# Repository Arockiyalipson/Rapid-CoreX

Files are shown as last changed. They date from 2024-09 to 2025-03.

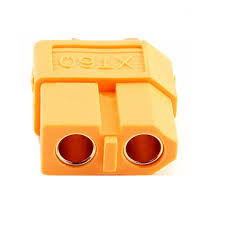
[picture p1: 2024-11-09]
Images/XT 60 FEMALE.jpg

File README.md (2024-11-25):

# Rapid_CoreX 





## Introduction

Rapid-CoreX is a versatile Rapid control prototyping (RCP) designed for embedded systems development, testing, and integration. It supports essential communication protocols and allows for easy connection and testing of various sensors or devices using MATLAB software. Rapid-CoreX is particularly useful for testing external parameters of Battery Management Systems (BMS), motor controllers, and other connected devices.

## Tools Used

- **KiCad:** Used for schematic capture and PCB layout design.
- **STM32CubeMX:** Used for setting up the pin map for the design

## Design Structure

```bash
Rapid-CoreX
        │
        ├───Design
        │
        ├───Images
        │
        ├───Library
        │   ├───Symbols
        │   ├───Footprint
        │   └───3D_Images
        ├───Manufacturing_files
        │   ├───Bom file
        │   ├───Component position files
        │   ├───Drill files
        │   ├───Gerber files
        │   └───Reference_material
        └───Reference
```

## Features

### Communication Protocols

Rapid-CoreX includes the following communication protocols for sensor connection, data collection, and interconnection:

#### Basic Protocols

- **SPI**: Serial Peripheral Interface for high-speed communication.
- **I2C**: Inter-Integrated Circuit for connecting multiple sensors.
- **UART**: Universal Asynchronous Receiver-Transmitter for serial communication.

#### Debugging

- **SWD**: Serial Wire Debug for in-circuit debugging and programming.

#### Data Collection and Interconnection Protocols

- **CAN**: Controller Area Network for real-time data exchange in automotive and industrial applications.
- **RS-485**: A robust standard for long-distance communication.
- **LIN**: Local Interconnect Network, used in automotive networks for communication between components.

All data collection protocols are isolated to ensure better protection and signal integrity.

### Communication Ports

Rapid-CoreX is equipped with various ports to facilitate connectivity:

- **2 x CAN** ports for network communication.
- **2 x RS-485** ports (USART) for long-distance and robust communication.
- **2 x LIN** ports for automotive applications.
- **1 x External SPI** ports for additional SPI device connectivity.

### GPIO Features

- **User LED**: Available for user-defined visual indication.

## Applications

Rapid-CoreX is ideal for:

- Testing external parameters of Battery Management Systems (BMS).
- Testing motor controllers.
- Integrating and testing various sensors.
- Development and testing of embedded systems that require robust and isolated communication.

## Getting Started

### Prerequisites

To use Rapid-CoreX, ensure you have the following:

- MATLAB software for interfacing and testing.
- Necessary drivers and libraries for STM32 Cortex-M4.

### Setup

1. Connect your sensors or sister devices to the appropriate communication ports on Rapid-CoreX.
2. Use MATLAB to interface with Rapid-CoreX for data collection and testing.
3. For debugging, connect through the SWD interface.

### Usage

1. Power on the Rapid-CoreX and ensure all connections are secure.
2. Implement a MATLAB Developed Algorithm in the board
3. Start collecting Data and Analyze it 

## Contact

For more information, please contact [Arockiya Lipson](https://www.linkedin.com/in/arockiya-lipson-458b12214).

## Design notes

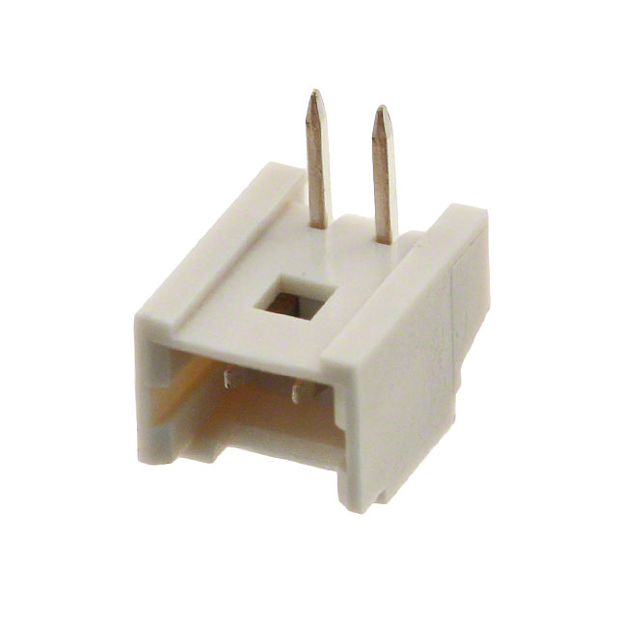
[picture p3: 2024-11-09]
Images/53048-0210_connector.jpg

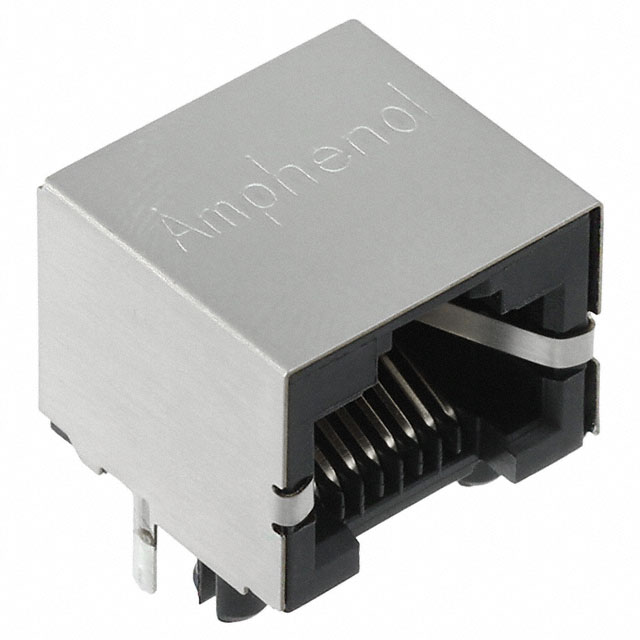
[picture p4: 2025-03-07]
Images/RJHSE5E80.jpg

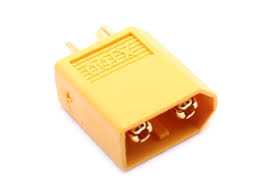
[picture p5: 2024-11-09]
Images/MALE.jpg

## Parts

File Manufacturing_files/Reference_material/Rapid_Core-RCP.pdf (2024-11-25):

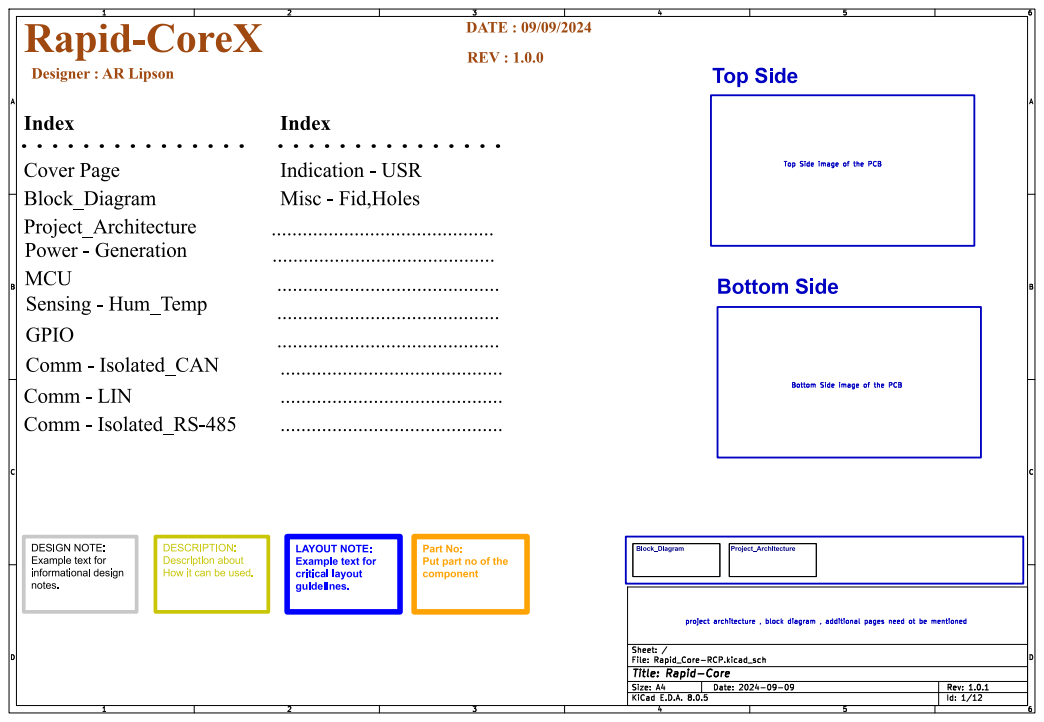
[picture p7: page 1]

Top Side image of the PCB Top Side

DESCRIPTION:
Description about
How it can be used.

Part No:
Put part no of the
component

Id: 1/12 Title: Rapid-Core

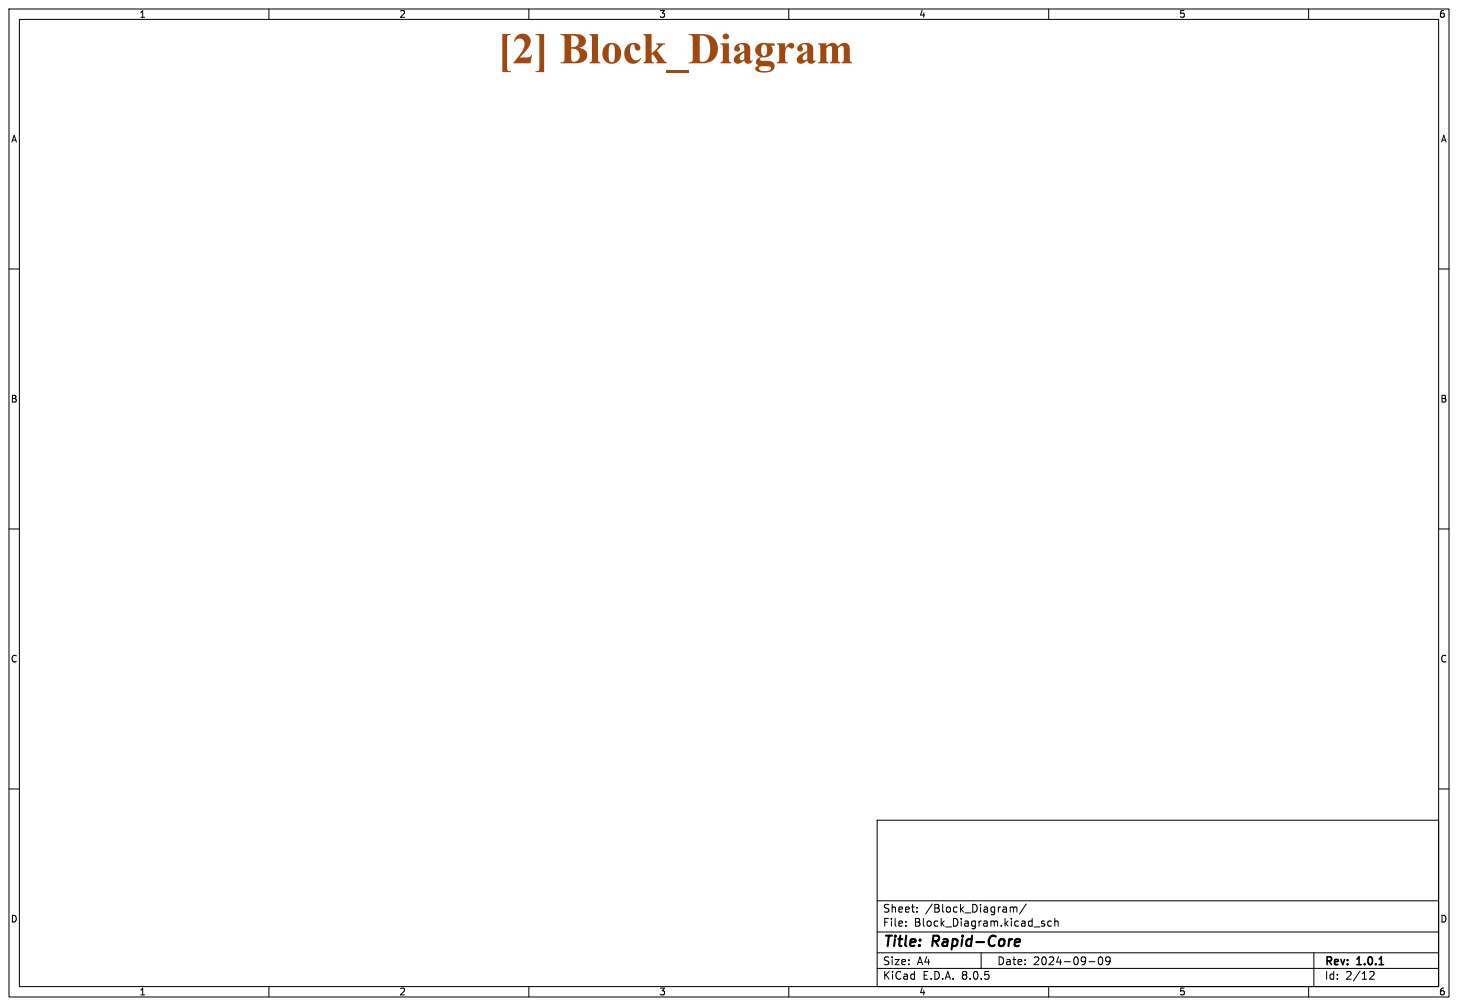
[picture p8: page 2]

File: Block_Diagram.kicad_sch Sheet: /Block_Diagram/
Id: 2/12 Title: Rapid-Core

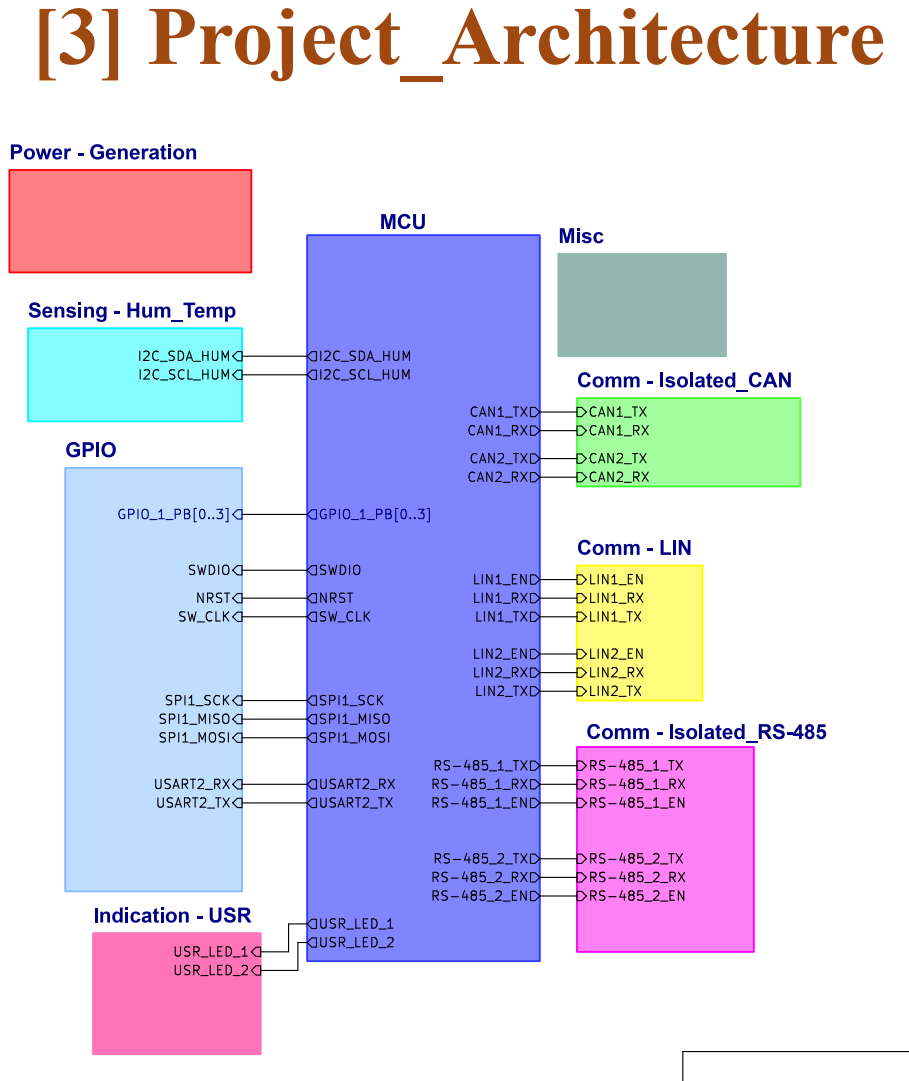
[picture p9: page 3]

RS-485_1_RX RS-485_1_TX RS-485_1_EN Comm - Isolated_RS-485

File: Project_Architecture.kicad_sch Sheet: /Project_Architecture/
Id: 3/12 Title: Rapid-Core

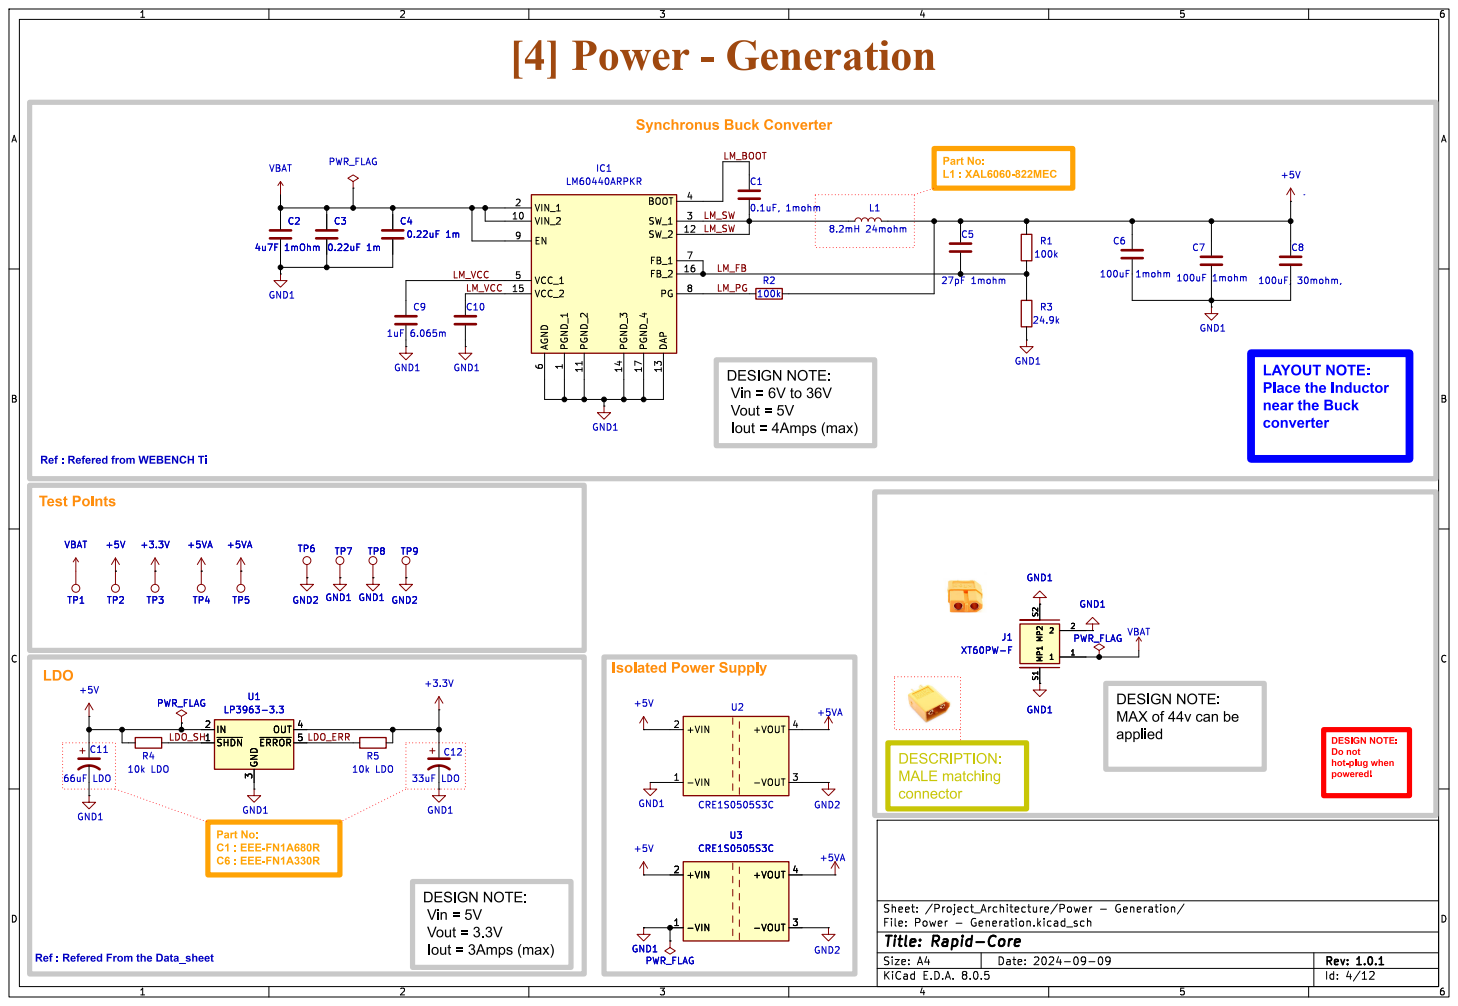
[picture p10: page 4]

LAYOUT NOTE:
Place the Inductor near the Buck

converter Part No: C1 : EEE-FN1A680R

Ref : Refered from WEBENCH Ti Test Points

MAX of 44v can be

Id: 4/12 Title: Rapid-Core

Ref : Refered From the Data_sheet

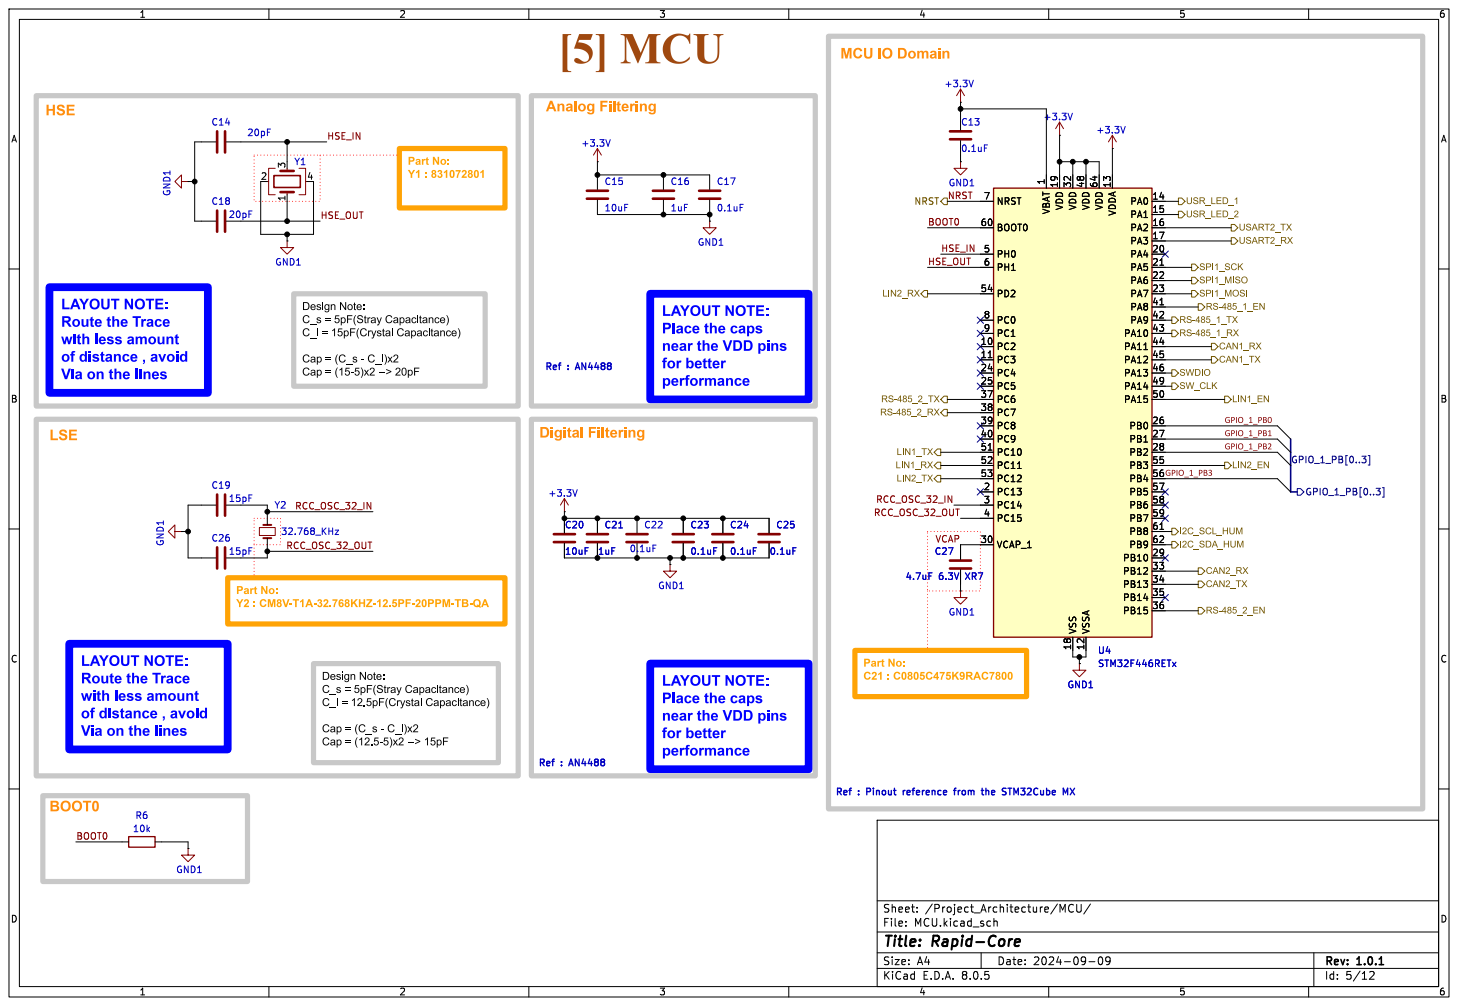
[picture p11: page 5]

1 PC2 10 PC3 11 VSSA 12 VDDA 13 PA0 14 PA1 15 PA2 16 PA3 17 VSS 18 VDD 19 PC13 2 PA4 20 PA5 21 PA6 22 PA7 23 PC4 24 PC5 25 PB0 26 PB1 27 PB2 28 PB10 29 PC14 3 VCAP_1 30 VDD 32 PB12 33 PB13 34 PB14 35 PB15 36 PC6 37 PC7 38 PC8 39 PC15 4 PC9 40 PA8 41 PA9 42 PA10 43 PA11 44 PA12 45 PA13 46 VDD 48 PA14 49 PH0 5 PA15 50 PC10 51 PC11 52 PC12 53 PD2 54 PB3 55 PB4 56 PB5 57 PB6 58 PB7 59 PH1 6 BOOT0 60 PB8 61 PB9 62 VDD 64 NRST 7 PC0 8 PC1 9 U4STM32F446RETx C23

1 PC2 10 PC3 11 VSSA 12 VDDA 13 PA0 14 PA1 15 PA2 16 PA3 17 VSS 18 VDD 19 PC13 2 PA4 20 PA5 21 PA6 22 PA7 23 PC4 24 PC5 25 PB0 26 PB1 27 PB2 28 PB10 29 PC14 3 VCAP_1 30 VDD 32 PB12 33 PB13 34 PB14 35 PB15 36 PC6 37 PC7 38 PC8 39 PC15 4 PC9 40 PA8 41 PA9 42 PA10 43 PA11 44 PA12 45 PA13 46 VDD 48 PA14 49 PH0 5 PA15 50 PC10 51 PC11 52 PC12 53 PD2 54 PB3 55 PB4 56 PB5 57 PB6 58 PB7 59 PH1 6 BOOT0 60 PB8 61 PB9 62 VDD 64 NRST 7 PC0 8 PC1 9 GND1 C23

BOOT0 Ref : Pinout reference from the STM32Cube MX BOOT0

LAYOUT NOTE:
Route the Trace
with less amount
of distance , avoid
Via on the lines

Design Note: C_s = 5pF(Stray Capacitance)

Place the caps near the VDD pins

Part No: Y2 : CM8V-T1A-32.768KHZ-12.5PF-20PPM-TB-QA

File: MCU.kicad_sch Sheet: /Project_Architecture/MCU/
Id: 5/12 Title: Rapid-Core

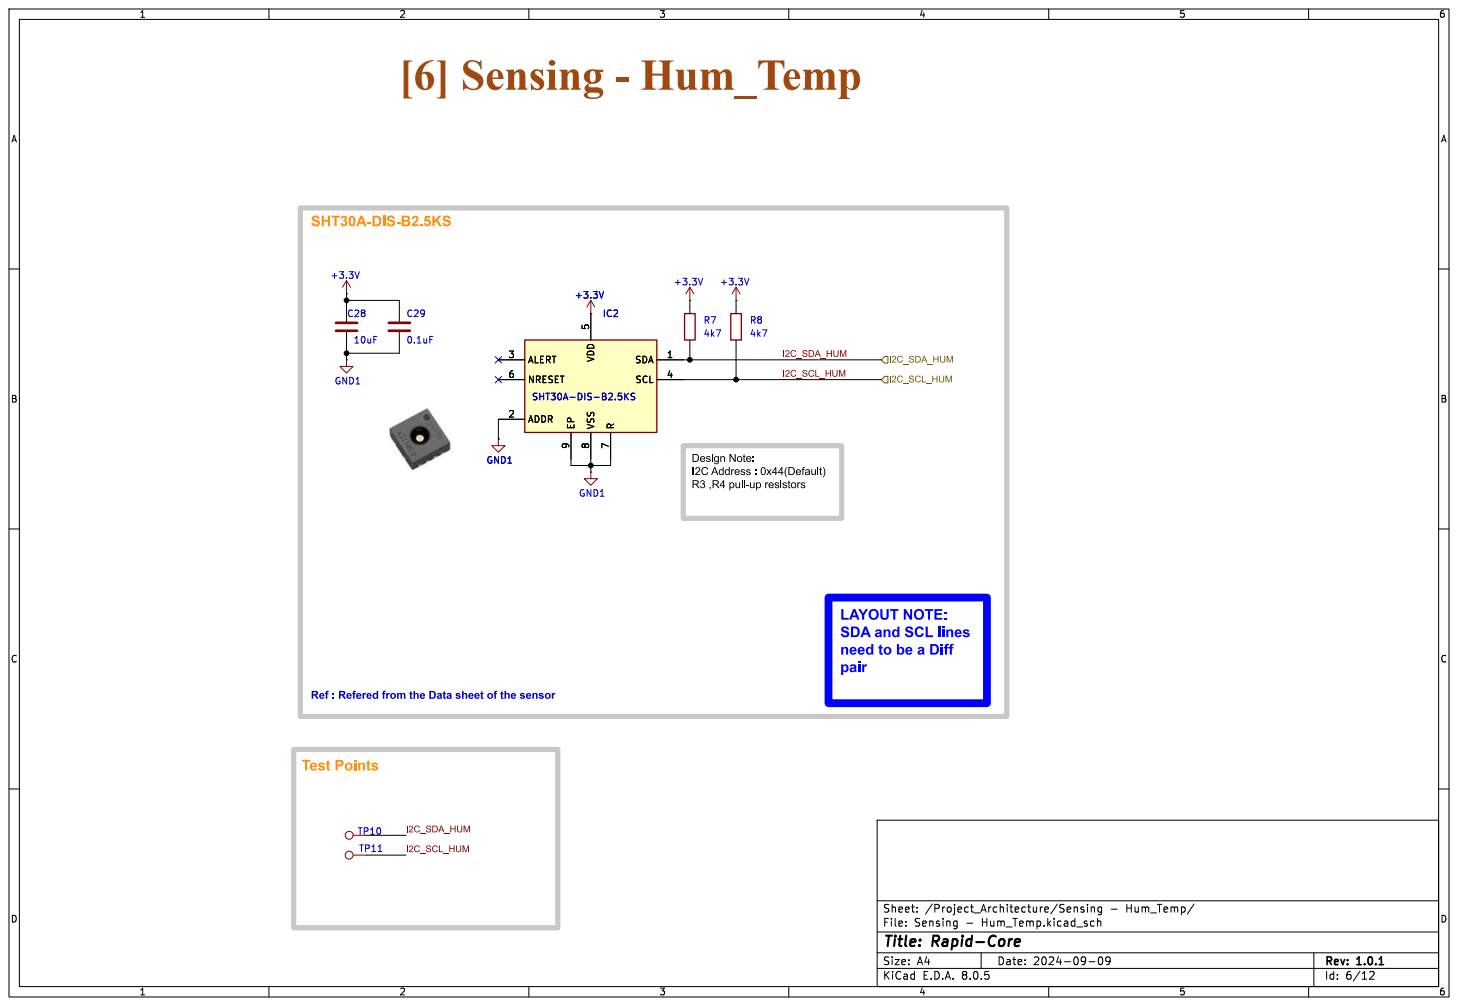
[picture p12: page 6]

SDA and SCL lines
need to be a Diff
pair

Ref : Refered from the Data sheet of the sensor Test Points

Id: 6/12 Title: Rapid-Core

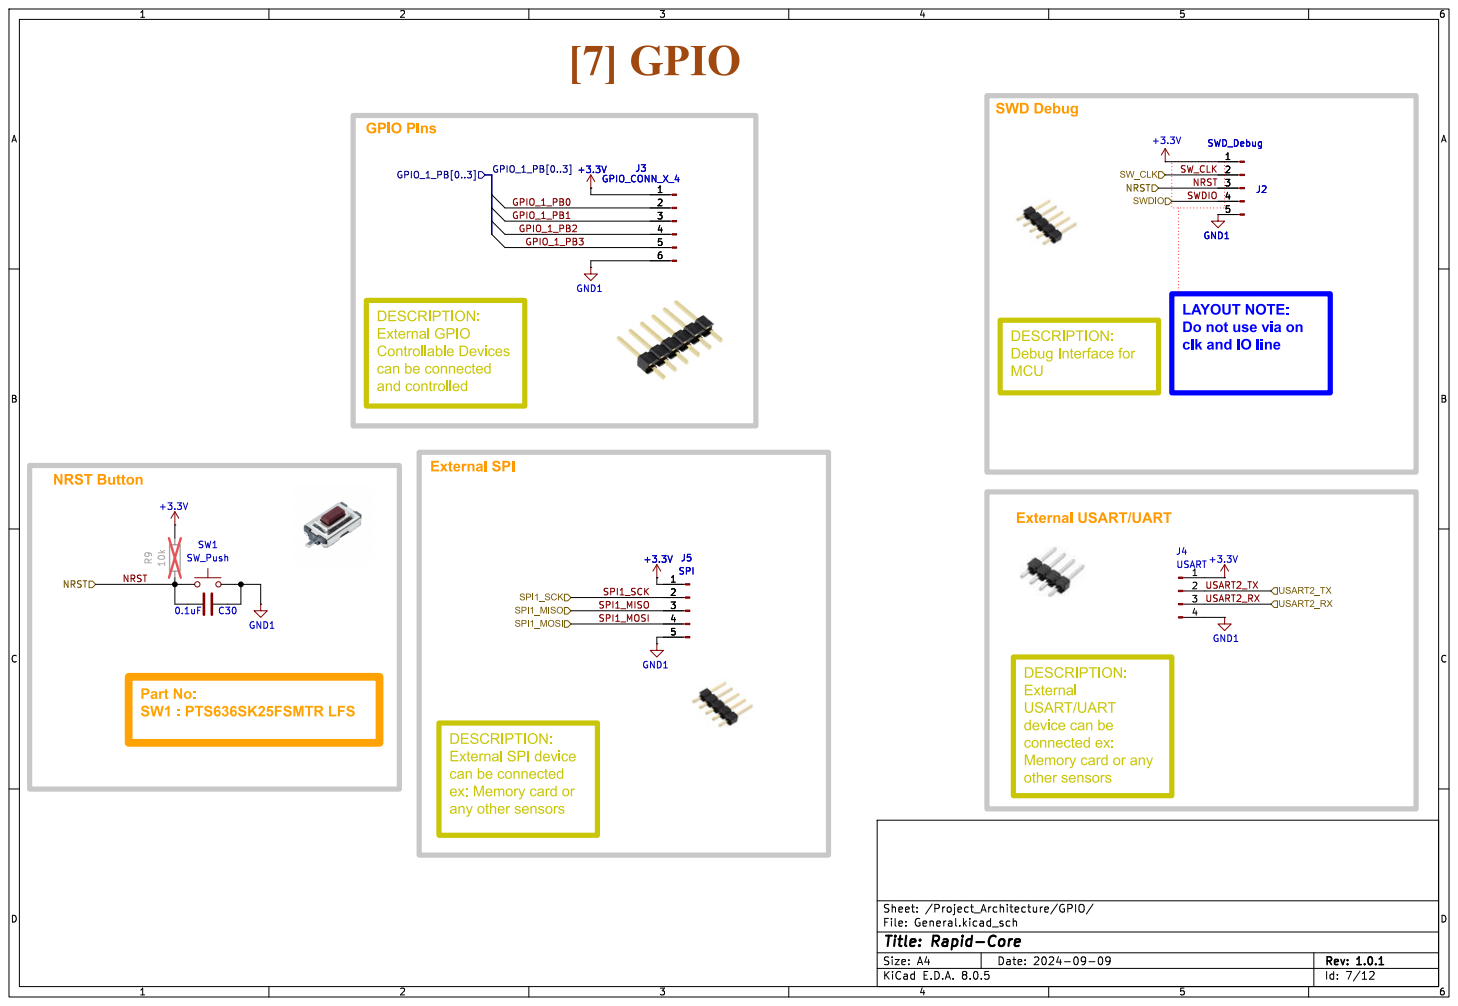
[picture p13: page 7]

SWD Debug

GPIO Pins | 5 5 6

Do not use via on

Debug Interface for | clk and IO line DESCRIPTION:

can be connected and controlled

File: General.kicad_sch Sheet: /Project_Architecture/GPIO/ GND1

DESCRIPTION:
External
USART/UART
device can be
connected ex: Memory card or any

Id: 7/12 Title: Rapid-Core

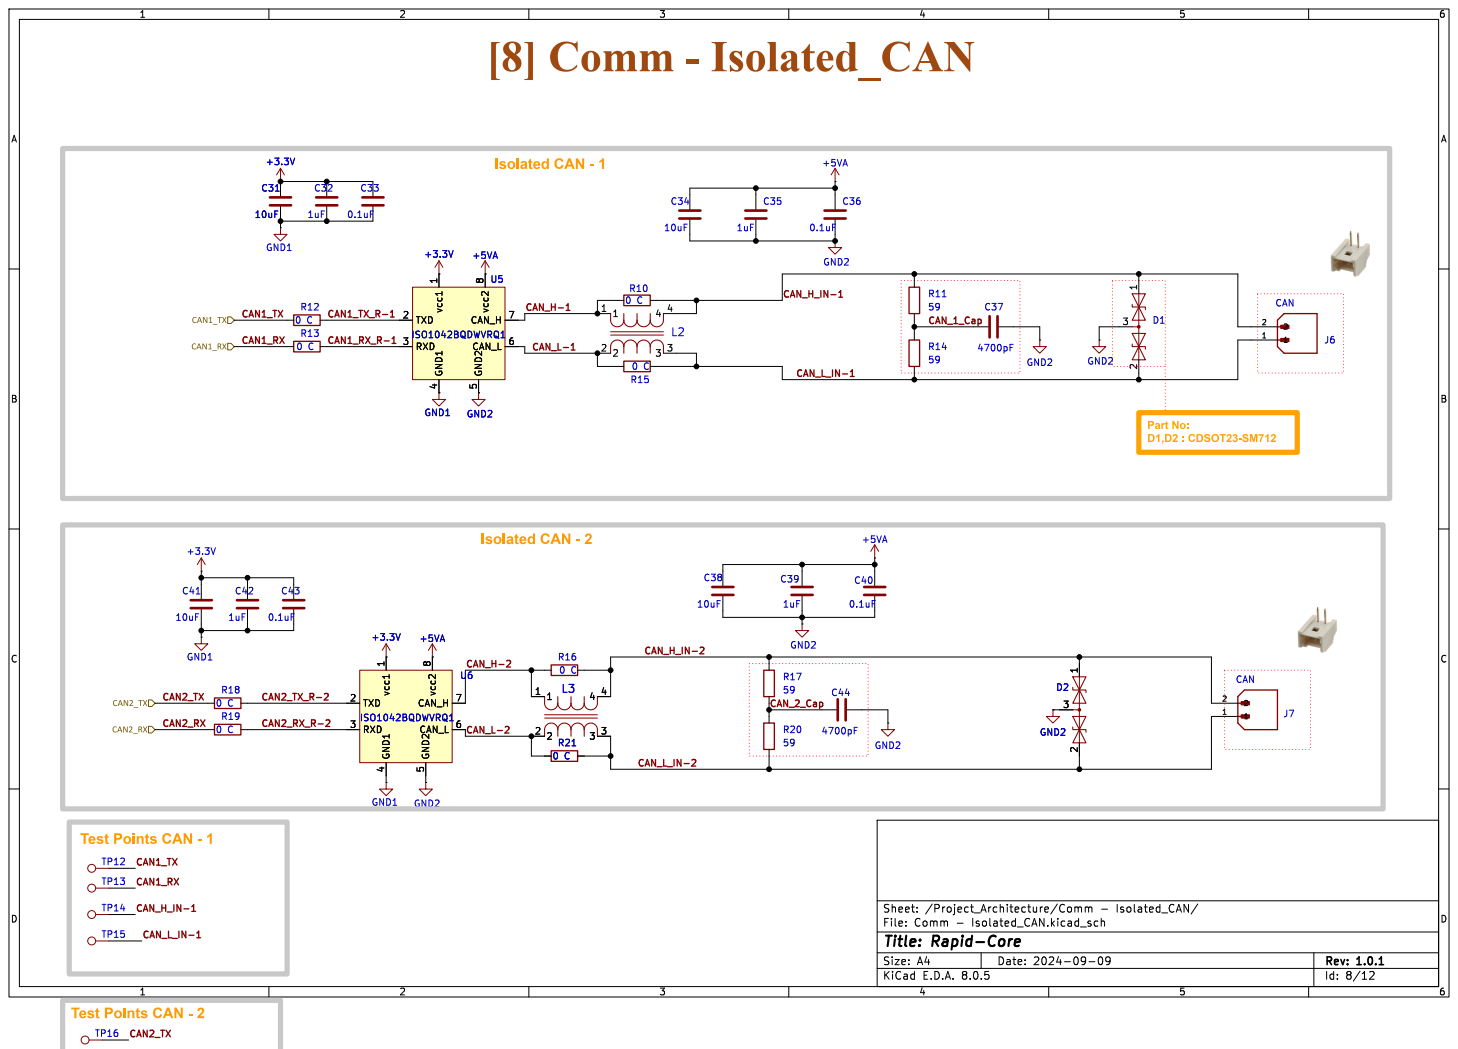
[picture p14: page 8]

Id: 8/12 Title: Rapid-Core


1. If J9 is closed the
tranceiver acts a Commander.

2. If J9 is open the

transceiver acts a Responder. Part No: D3 : 1N4448WSF-7

Id: 9/12 Title: Rapid-Core


RS-485_B_IN-1 RS-485_2_TX_R-2 Test Points RS_485 - 1

Id: 10/12 Title: Rapid-Core


LED_2_R [11]Indication- USR
Size : 0603 DESIGN NOTE : USR LED(GREEN): Vf = 2V R =(5V - 2V)/20mA = 150Ohm

Id: 11/12 Title: Rapid-Core


File: Misc.kicad_sch Sheet: /Project_Architecture/Misc/
Id: 12/12 Title: Rapid-Core

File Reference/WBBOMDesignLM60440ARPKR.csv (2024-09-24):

Part | Manufacturer | Part Number | Quantity | Price ($) | Footprint (mm²) | Description
Cboot | MuRata | GRM155R71A104KA01D | 1 | 0.01 | 3 | Cap: 100 nF Total Derated Cap: 100 nF VDC: 10 V ESR: 1 mΩ Package: 0402
Cvcc | MuRata | GRM188R60J105KA01D | 1 | 0.01 | 4.68 | Cap: 1 µF Total Derated Cap: 1 µF VDC: 6.3 V ESR: 6.07 mΩ Package: 0
Cout | MuRata | GRM32EC80J107ME20L | 2 | 0.17 | 14.7 | Cap: 100 µF Total Derated Cap: 130 µF VDC: 6.3 V ESR: 1 mΩ Package: 1210
Coutx | MuRata | GRM188R71C104KA01D | 1 | 0.01 | 4.68 | Cap: 100 nF Total Derated Cap: 100 nF VDC: 16 V ESR: 30 mΩ Package: 0603
Cin | TDK | C2012X5R1H475K125AB | 1 | 0.12 | 6.75 | Cap: 4.7 µF Total Derated Cap: 1.2 µF VDC: 50 V ESR: 1 mΩ Package: 0805
U1 | Texas Instruments | LM60440ARPKR | 1 | 0.903 | 12
L1 | Coilcraft | XAL6060-822MEB | 1 | 0.82 | 71.56 | L: 8.2 µH DCR: 24 mΩ IDC: 8 A
Cinx | Taiyo Yuden | UMK212B7224KG-T | 1 | 0.02 | 6.75 | Cap: 220 nF Total Derated Cap: 220 nF VDC: 50 V ESR: 1 mΩ Package: 0805
Cinx_ch1 | Taiyo Yuden | UMK212B7224KG-T | 1 | 0.02 | 6.75 | Cap: 220 nF Total Derated Cap: 220 nF VDC: 50 V ESR: 1 mΩ Package: 0805
Rfbt | Vishay-Dale | CRCW0402100KFKED | 1 | 0.01 | 3 | Resistance: 100 kΩ Tolerance: 1.0% Power: 63 mW
Rfbb | Vishay-Dale | CRCW040243K2FKED | 1 | 0.01 | 3 | Resistance: 43.2 kΩ Tolerance: 1.0% Power: 63 mW
Rpg | Vishay-Dale | CRCW0603100KFKEA | 1 | 0.01 | 4.68 | Resistance: 100 kΩ Tolerance: 1.0% Power: 100 mW
Cff | MuRata | GRM1555C1H270JA01D | 1 | 0.01 | 3 | Cap: 27 pF Total Derated Cap: 27 pF VDC: 50 V ESR: 1 mΩ Package: 0402

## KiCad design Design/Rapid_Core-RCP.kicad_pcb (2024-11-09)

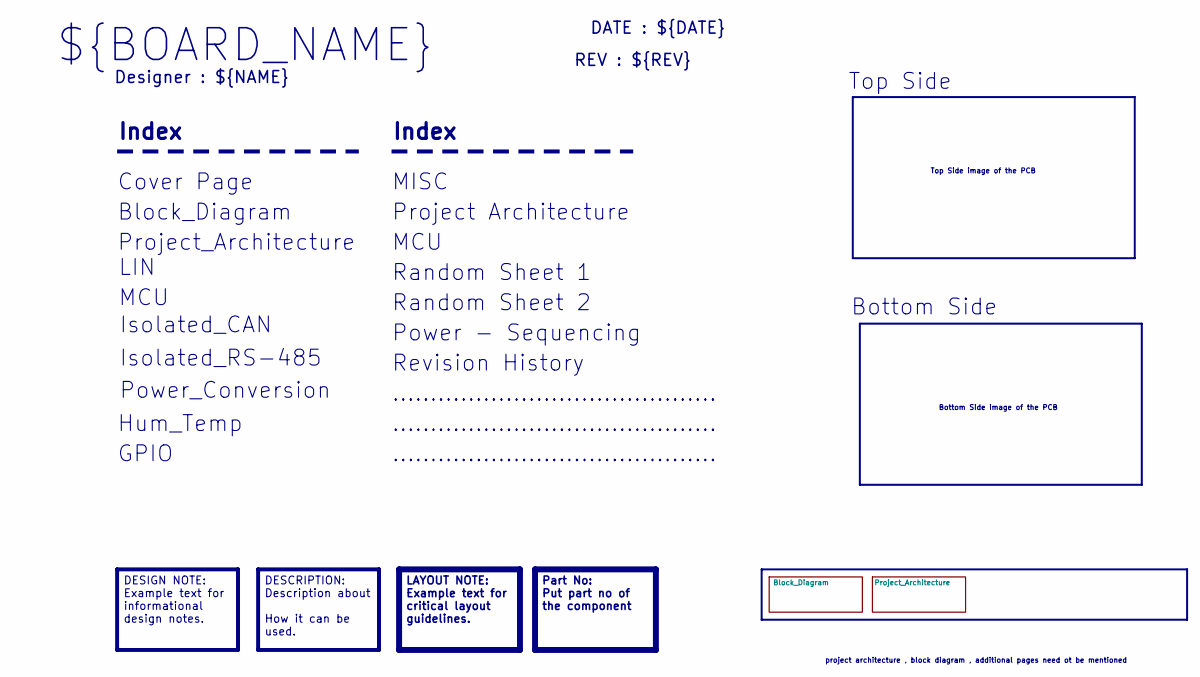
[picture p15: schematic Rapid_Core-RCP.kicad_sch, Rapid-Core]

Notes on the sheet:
DESCRIPTION: Description about How it can be used.
Part No: Put part no of the component
DESIGN NOTE: Example text for informational design notes.
LAYOUT NOTE: Example text for critical layout guidelines.
...........................................
Top Side image of the PCB
MISC
Power_Conversion
Designer : ${NAME}
Random Sheet 1
Revision History
Hum_Temp
project architecture , block diagram , additional pages need ot be mentioned
Cover Page
Power - Sequencing
Bottom Side image of the PCB
DATE : ${DATE}
Project_Architecture
Top Side
Isolated_RS-485
${BOARD_NAME}
Index
Bottom Side
REV : ${REV}
GPIO
Isolated_CAN
Random Sheet 2
MCU
Project Architecture
LIN
Block_Diagram

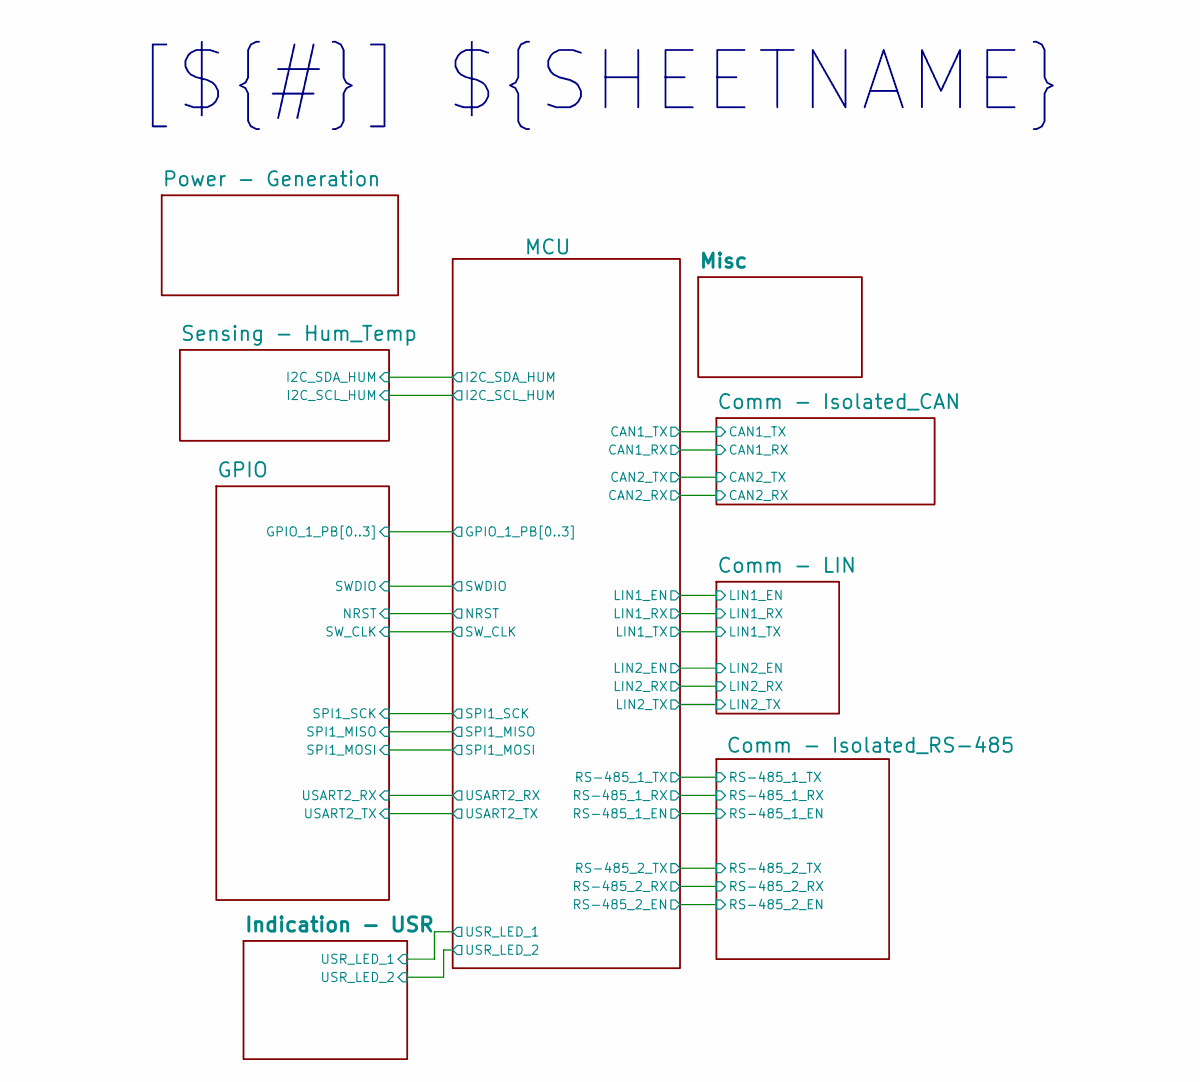
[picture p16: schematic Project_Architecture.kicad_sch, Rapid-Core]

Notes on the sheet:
[${#}] ${SHEETNAME}

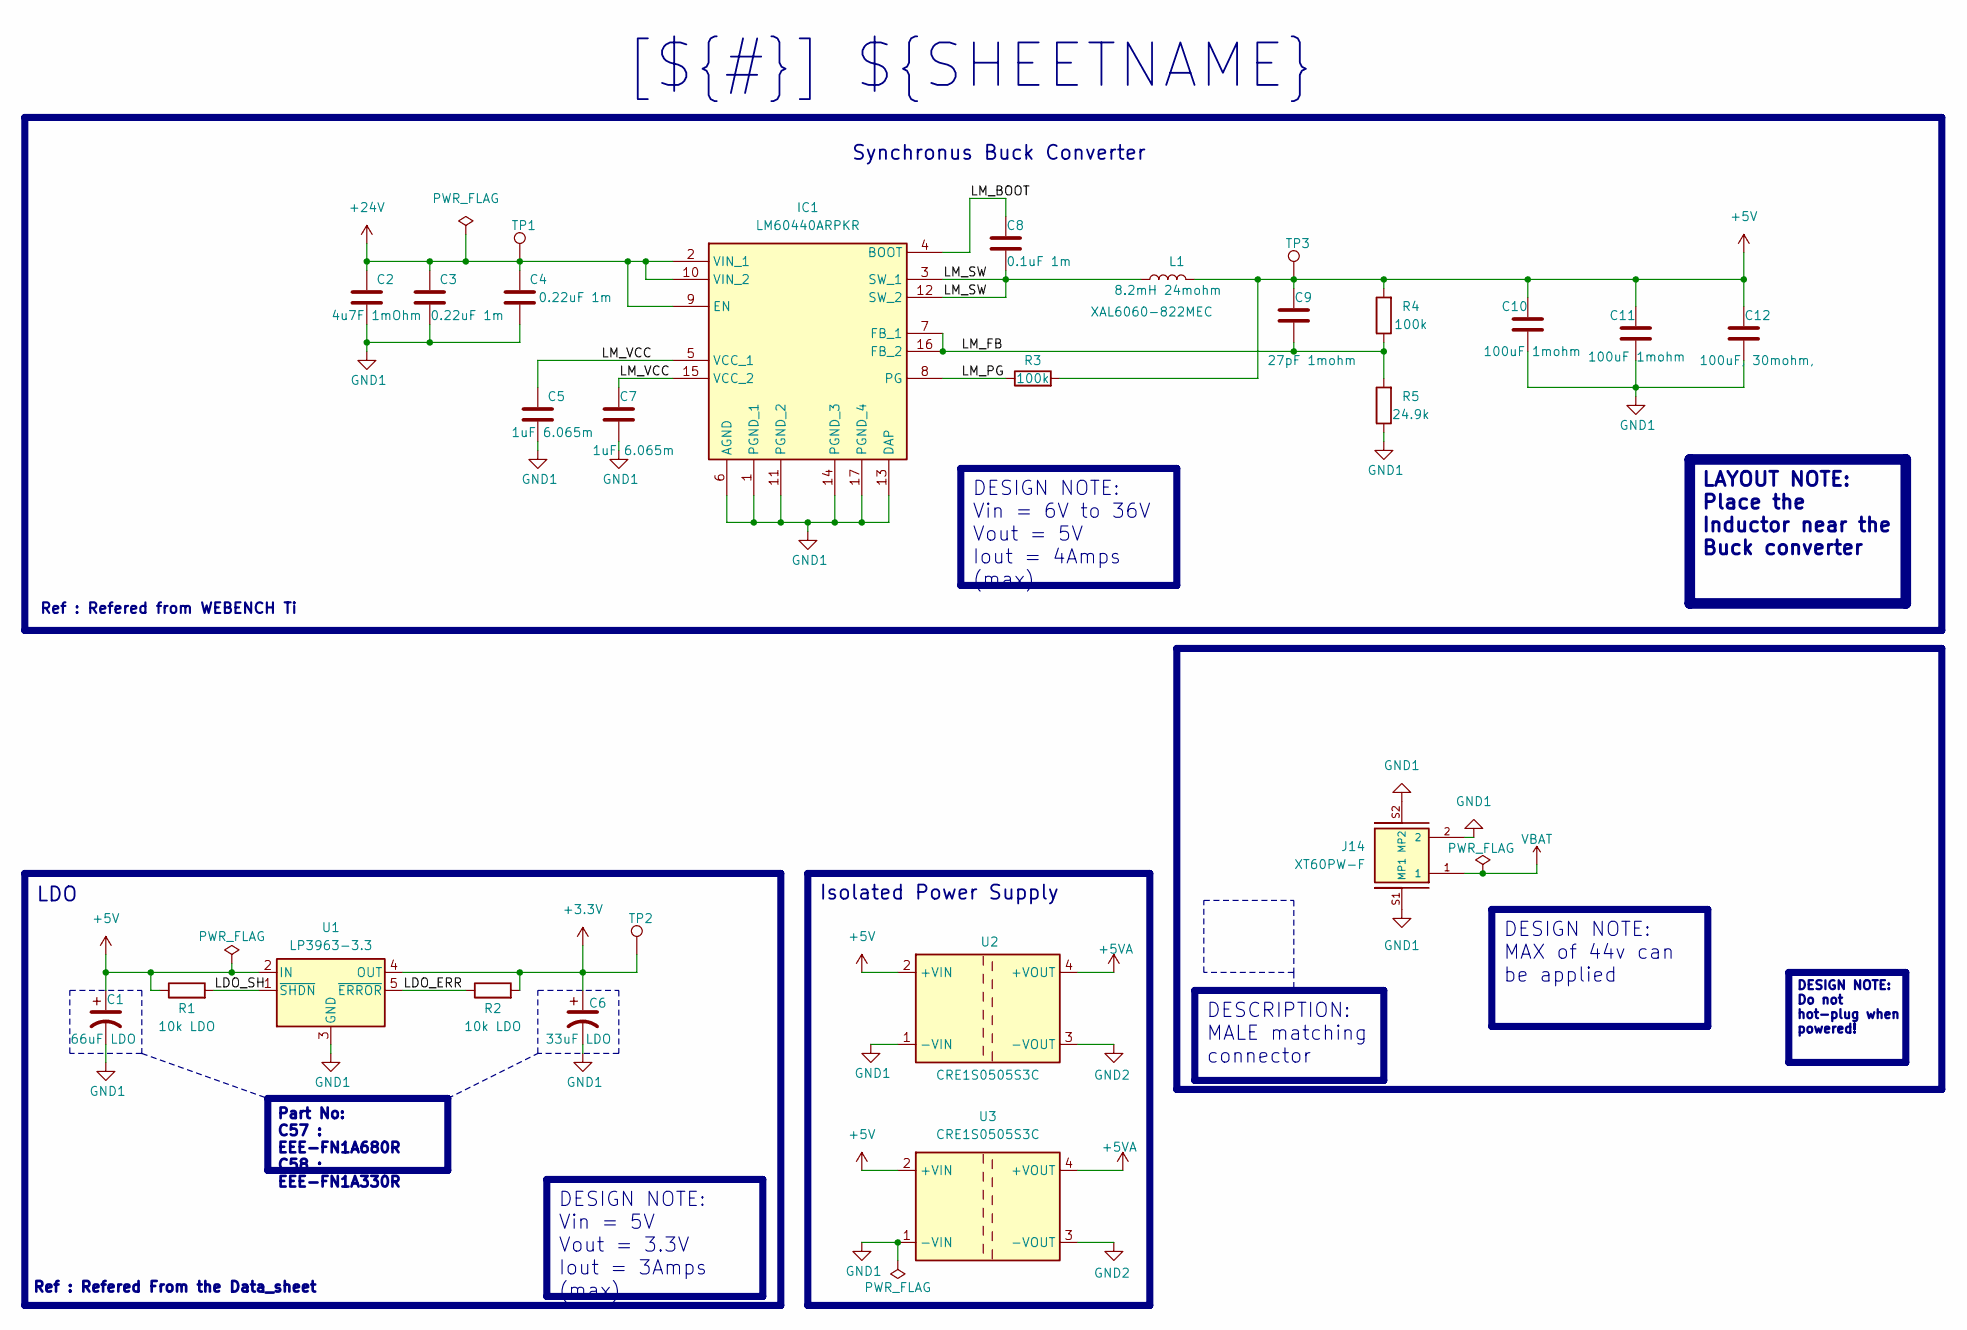
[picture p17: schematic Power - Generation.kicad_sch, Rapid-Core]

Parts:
C1: 66uF LDO; CP_Elec_5x5.8
C2: 4u7F 1mOhm; C_0805_2012Metric_Pad1.18x1.45mm_HandSolder
C3, C4: 0.22uF 1m; C_0603_1608Metric_Pad1.08x0.95mm_HandSolder
C5, C7: 1uF 6.065m; C_0603_1608Metric_Pad1.08x0.95mm_HandSolder
C6: 33uF LDO; CP_Elec_4x5.8
C8: 0.1uF 1m; C_0603_1608Metric_Pad1.08x0.95mm_HandSolder
C9: 27pF 1mohm; C_0805_2012Metric_Pad1.18x1.45mm_HandSolder
C10, C11: 100uF 1mohm; C_0805_2012Metric_Pad1.18x1.45mm_HandSolder
C12: 100uF, 30mohm,; C_0805_2012Metric_Pad1.18x1.45mm_HandSolder
IC1: LM60440ARPKR; LM60440AQRPKRQ1; Mouser Part Number 595-LM60440ARPKR
J14: XT60PW-F; AMASS_XT60PW-F
L1: 8.2mH 24mohm; L_Coilcraft_XAL6060-XXX; MANUFACTURER PART NO XAL6060-822MEC
R1, R2: 10k LDO; R_0805_2012Metric_Pad1.20x1.40mm_HandSolder
R3, R4: 100k; R_0805_2012Metric_Pad1.20x1.40mm_HandSolder
R5: 24.9k; R_0805_2012Metric_Pad1.20x1.40mm_HandSolder
TP1, TP2, TP3: TestPoint; TestPoint_Pad_D1.0mm
U1: LP3963-3.3; TO-263-5_TabPin3
U2, U3: CRE1S0505S3C; Converter_DCDC_Murata_CRE1xxxxxx3C_THT

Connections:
+3.3V: C6.1, R2.2, TP2.1, U1.4 (OUT); also elsewhere on the board
+5V: C1.1, C9.1, C10.1, C11.1, C12.1, L1.2, R1.1, R3.2, R4.2, TP3.1, U1.2 (IN), U2.2 (+VIN), U3.2 (+VIN); also elsewhere on the board
+5VA: U2.4 (+VOUT), U3.4 (+VOUT); also elsewhere on the board
+24V: C2.1, C3.1, C4.1, IC1.2 (VIN_1), IC1.9 (EN), IC1.10 (VIN_2), TP1.1
/Project_Architecture/Power - Generation/LDO_ERR: R2.1, U1.5 (~ERROR)
/Project_Architecture/Power - Generation/LDO_SH: R1.2, U1.1 (~SHDN)
/Project_Architecture/Power - Generation/LM_BOOT: C8.1, IC1.4 (BOOT)
/Project_Architecture/Power - Generation/LM_FB: C9.2, IC1.7 (FB_1), IC1.16 (FB_2), R4.1, R5.2
/Project_Architecture/Power - Generation/LM_PG: IC1.8 (PG), R3.1
/Project_Architecture/Power - Generation/LM_SW: C8.2, IC1.3 (SW_1), IC1.12 (SW_2), L1.1
/Project_Architecture/Power - Generation/LM_VCC: C5.1, C7.1, IC1.5 (VCC_1), IC1.15 (VCC_2)
GND1: C1.2, C2.2, C3.2, C4.2, C5.2, C6.2, C7.2, C10.2, C11.2, C12.2, IC1.1 (PGND_1), IC1.6 (AGND), IC1.11 (PGND_2), IC1.13 (DAP), IC1.14 (PGND_3), IC1.17 (PGND_4), J14.2, J14.S1 (MP1), J14.S2 (MP2), R5.1, U1.3 (GND), U2.1 (-VIN), U3.1 (-VIN); also elsewhere on the board
GND2: U2.3 (-VOUT), U3.3 (-VOUT); also elsewhere on the board
VBAT: J14.1

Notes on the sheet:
DESIGN NOTE: Vin = 5V Vout = 3.3V Iout = 3Amps (max)
DESIGN NOTE: Vin = 6V to 36V Vout = 5V Iout = 4Amps (max)
DESIGN NOTE: MAX of 44v can be applied
LAYOUT NOTE: Place the Inductor near the Buck converter
Part No: C57 : EEE-FN1A680R C58 : EEE-FN1A330R
DESCRIPTION: MALE matching connector
DESIGN NOTE: Do not hot-plug when powered!
[${#}] ${SHEETNAME}
Isolated Power Supply
LDO
Ref : Refered From the Data_sheet
Synchronus Buck Converter
Ref : Refered from WEBENCH Ti

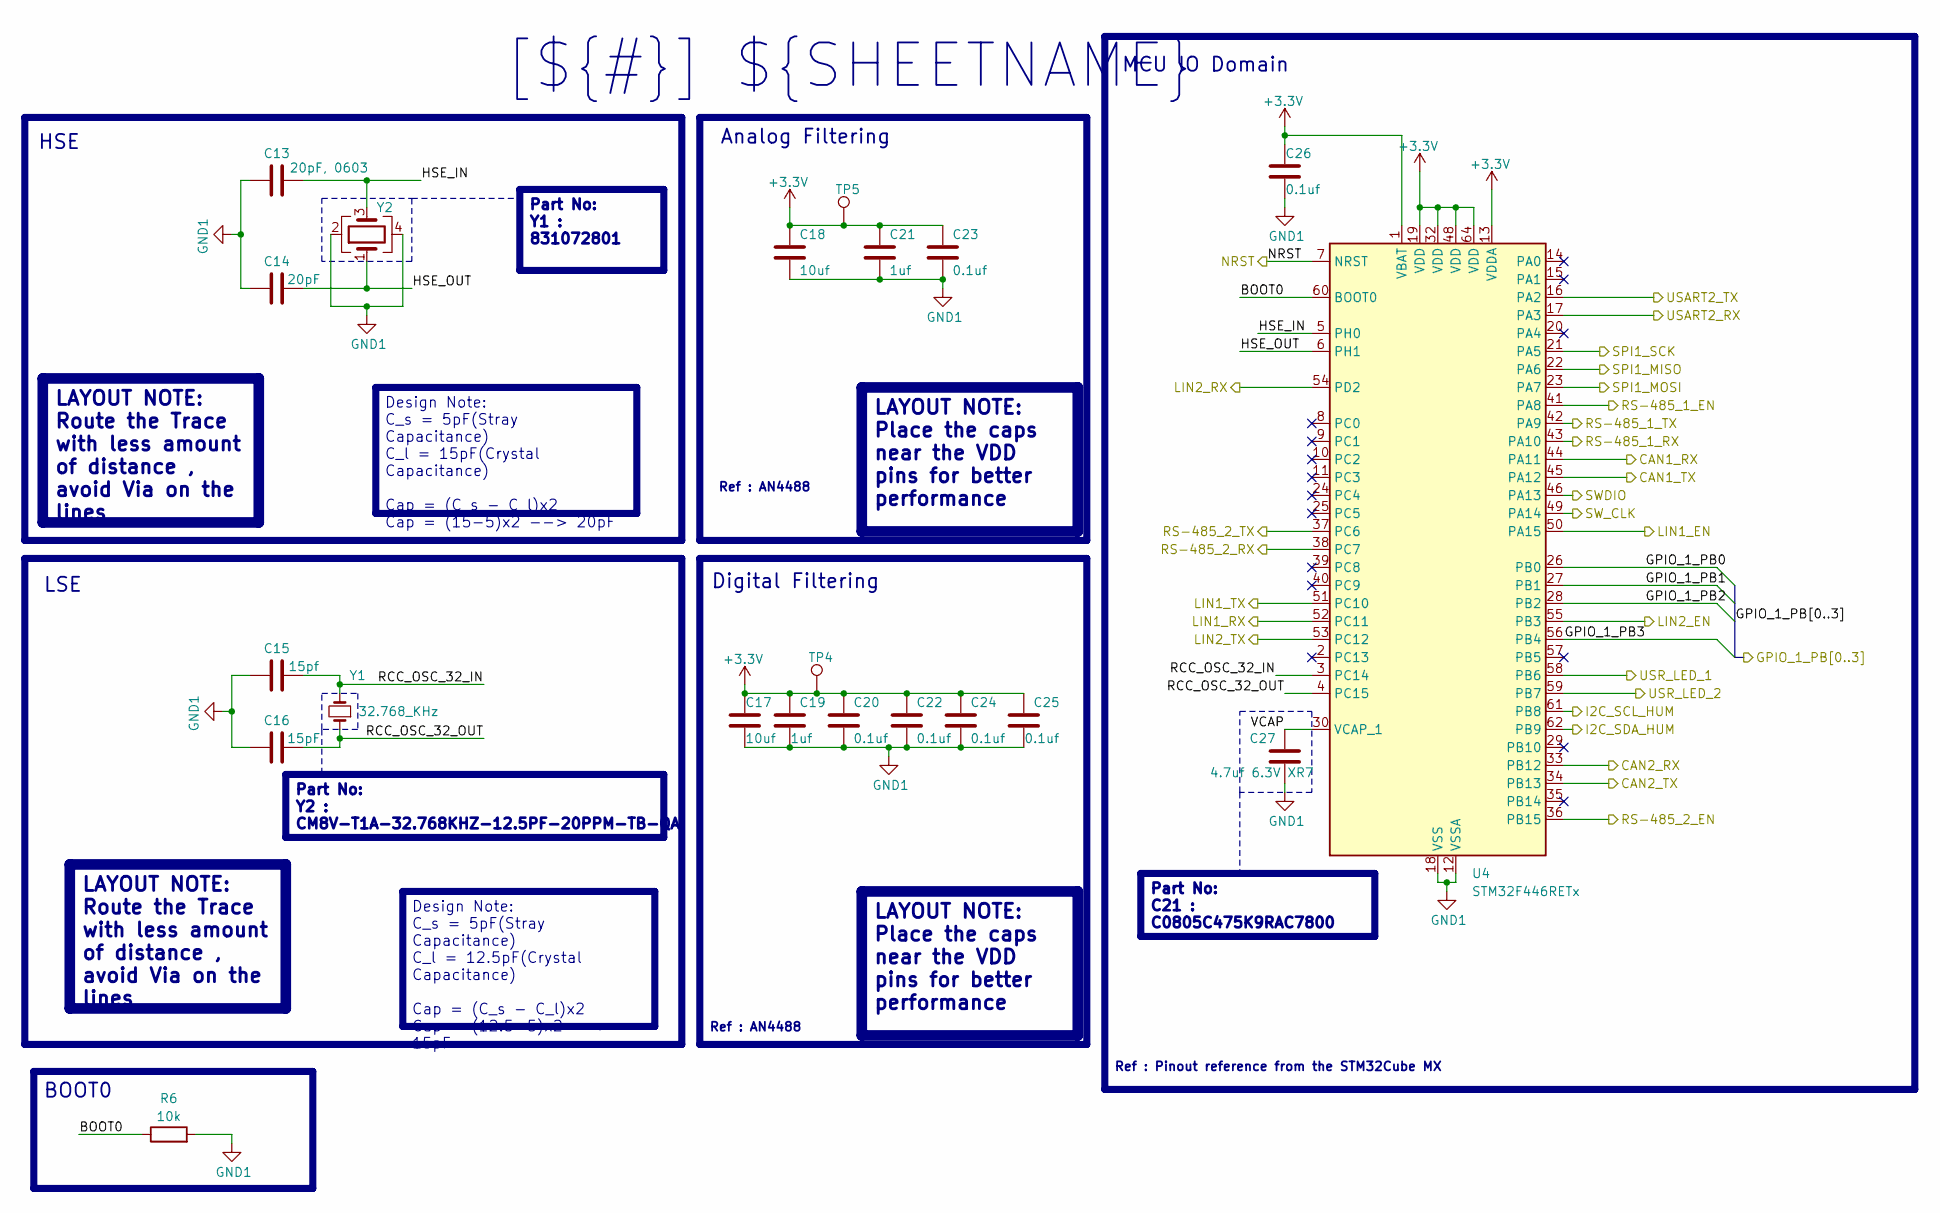
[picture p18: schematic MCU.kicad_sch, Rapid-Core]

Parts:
C13: 20pF, 0603; C_0603_1608Metric
C14: 20pF; C_0603_1608Metric
C15: 15pf; C_0603_1608Metric
C16: 15pF; C_0603_1608Metric
C17, C18: 10uf; C_0805_2012Metric_Pad1.18x1.45mm_HandSolder
C19, C21: 1uf; C_0603_1608Metric_Pad1.08x0.95mm_HandSolder
C20, C22, C23, C24, C25, C26: 0.1uf; C_0603_1608Metric_Pad1.08x0.95mm_HandSolder
C27: 4.7uf 6.3V XR7; C_0805_2012Metric_Pad1.18x1.45mm_HandSolder
R6: 10k; R_0805_2012Metric_Pad1.20x1.40mm_HandSolder
TP4, TP5: TestPoint; TestPoint_Pad_D1.0mm
U4: STM32F446RETx; LQFP-64_10x10mm_P0.5mm
Y1: 32.768_KHz; Crystal_SMD_MicroCrystal_CC8V-T1A-2Pin_2.0x1.2mm
Y2: Crystal_GND24; Crystal_SMD_2520-4Pin_2.5x2.0mm

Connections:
+3.3V: C17.1, C18.1, C19.1, C20.1, C21.1, C22.1, C23.1, C24.1, C25.1, C26.1, TP4.1, TP5.1, U4.1 (VBAT), U4.13 (VDDA), U4.19 (VDD), U4.32 (VDD), U4.48 (VDD), U4.64 (VDD); also elsewhere on the board
/Project_Architecture/Comm - Isolated_CAN/CAN1_RX: U4.44 (PA11); also elsewhere on the board
/Project_Architecture/Comm - Isolated_CAN/CAN1_TX: U4.45 (PA12); also elsewhere on the board
/Project_Architecture/Comm - Isolated_CAN/CAN2_RX: U4.33 (PB12); also elsewhere on the board
/Project_Architecture/Comm - Isolated_CAN/CAN2_TX: U4.34 (PB13); also elsewhere on the board
/Project_Architecture/Comm - Isolated_RS-485/RS-485_1_EN: U4.41 (PA8); also elsewhere on the board
/Project_Architecture/Comm - Isolated_RS-485/RS-485_1_RX: U4.43 (PA10); also elsewhere on the board
/Project_Architecture/Comm - Isolated_RS-485/RS-485_1_TX: U4.42 (PA9); also elsewhere on the board
/Project_Architecture/Comm - Isolated_RS-485/RS-485_2_EN: U4.36 (PB15); also elsewhere on the board
/Project_Architecture/Comm - Isolated_RS-485/RS-485_2_RX: U4.38 (PC7); also elsewhere on the board
/Project_Architecture/Comm - Isolated_RS-485/RS-485_2_TX: U4.37 (PC6); also elsewhere on the board
/Project_Architecture/Comm - LIN/LIN1_EN: U4.50 (PA15); also elsewhere on the board
/Project_Architecture/Comm - LIN/LIN1_RX: U4.52 (PC11); also elsewhere on the board
/Project_Architecture/Comm - LIN/LIN1_TX: U4.51 (PC10); also elsewhere on the board
/Project_Architecture/Comm - LIN/LIN2_EN: U4.55 (PB3); also elsewhere on the board
/Project_Architecture/Comm - LIN/LIN2_RX: U4.54 (PD2); also elsewhere on the board
/Project_Architecture/Comm - LIN/LIN2_TX: U4.53 (PC12); also elsewhere on the board
/Project_Architecture/GPIO/GPIO_1_PB0: U4.26 (PB0); also elsewhere on the board
/Project_Architecture/GPIO/GPIO_1_PB1: U4.27 (PB1); also elsewhere on the board
/Project_Architecture/GPIO/GPIO_1_PB2: U4.28 (PB2); also elsewhere on the board
/Project_Architecture/GPIO/GPIO_1_PB3: U4.56 (PB4); also elsewhere on the board
/Project_Architecture/GPIO/NRST: U4.7 (NRST); also elsewhere on the board
/Project_Architecture/GPIO/SPI1_MISO: U4.22 (PA6); also elsewhere on the board
/Project_Architecture/GPIO/SPI1_MOSI: U4.23 (PA7); also elsewhere on the board
/Project_Architecture/GPIO/SPI1_SCK: U4.21 (PA5); also elsewhere on the board
/Project_Architecture/GPIO/SWDIO: U4.46 (PA13); also elsewhere on the board
/Project_Architecture/GPIO/SW_CLK: U4.49 (PA14); also elsewhere on the board
/Project_Architecture/GPIO/USART2_RX: U4.17 (PA3); also elsewhere on the board
/Project_Architecture/GPIO/USART2_TX: U4.16 (PA2); also elsewhere on the board
/Project_Architecture/Indication - USR/USR_LED_1: U4.58 (PB6); also elsewhere on the board
/Project_Architecture/Indication - USR/USR_LED_2: U4.59 (PB7); also elsewhere on the board
/Project_Architecture/MCU/BOOT0: R6.1, U4.60 (BOOT0)
/Project_Architecture/MCU/HSE_IN: C13.2, U4.5 (PH0), Y2.3
/Project_Architecture/MCU/HSE_OUT: C14.2, U4.6 (PH1), Y2.1
/Project_Architecture/MCU/I2C_SCL_HUM: U4.61 (PB8); also elsewhere on the board
/Project_Architecture/MCU/I2C_SDA_HUM: U4.62 (PB9); also elsewhere on the board
/Project_Architecture/MCU/RCC_OSC_32_IN: C15.2, U4.3 (PC14), Y1.2
/Project_Architecture/MCU/RCC_OSC_32_OUT: C16.2, U4.4 (PC15), Y1.1
/Project_Architecture/MCU/VCAP: C27.1, U4.30 (VCAP_1)
GND1: C13.1, C14.1, C15.1, C16.1, C17.2, C18.2, C19.2, C20.2, C21.2, C22.2, C23.2, C24.2, C25.2, C26.2, C27.2, R6.2, U4.12 (VSSA), U4.18 (VSS), U4.31 (VSS), U4.47 (VSS), U4.63 (VSS), Y2.2, Y2.4; also elsewhere on the board

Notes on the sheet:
Design Note: C_s = 5pF(Stray Capacitance) C_l = 12.5pF(Crystal Capacitance) Cap = (C_s - C_l)x2 Cap = (12.5-5)x2 --> 15pF
Design Note: C_s = 5pF(Stray Capacitance) C_l = 15pF(Crystal Capacitance) Cap = (C_s - C_l)x2 Cap = (15-5)x2 --> 20pF
Part No: C21 : C0805C475K9RAC7800
Part No: Y2 : CM8V-T1A-32.768KHZ-12.5PF-20PPM-TB-QA
LAYOUT NOTE: Route the Trace with less amount of distance , avoid Via on the lines
LAYOUT NOTE: Place the caps near the VDD pins for better performance
Part No: Y1 : 831072801
Ref : AN4488
[${#}] ${SHEETNAME}
Digital Filtering
Analog Filtering
Ref : Pinout reference from the STM32Cube MX
BOOT0
LSE
MCU IO Domain
HSE

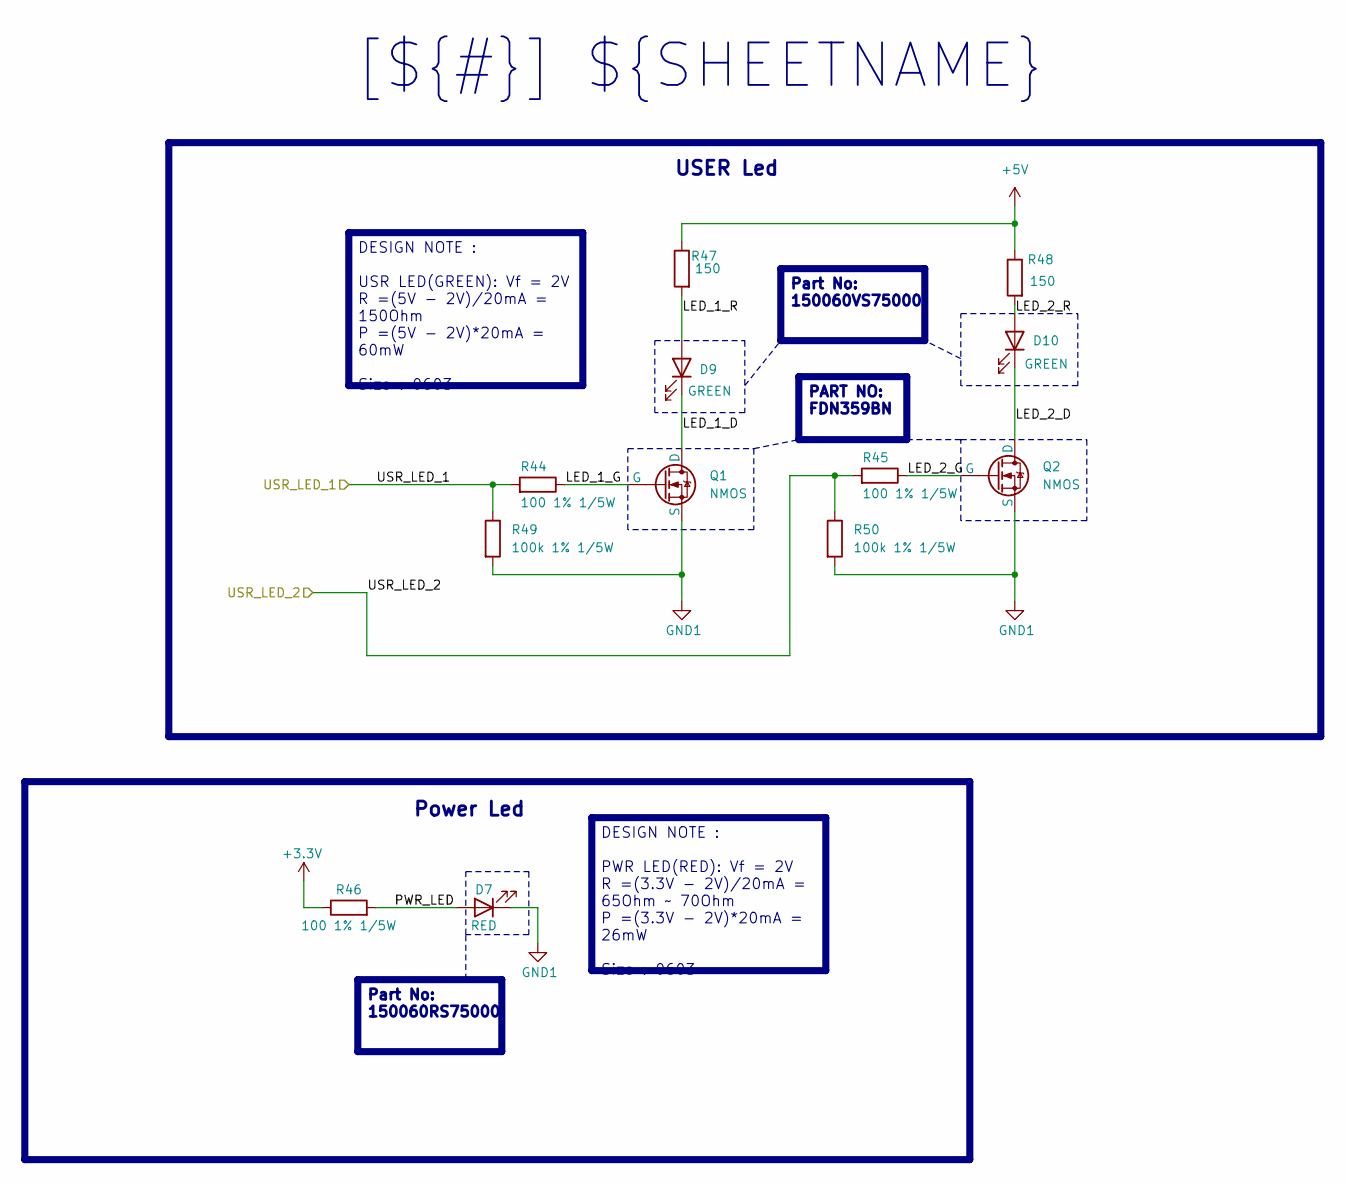
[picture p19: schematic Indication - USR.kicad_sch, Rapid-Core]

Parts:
D7: RED; LED_0603_1608Metric_Pad1.05x0.95mm_HandSolder
D9, D10: GREEN; LED_0603_1608Metric_Pad1.05x0.95mm_HandSolder
Q1, Q2: NMOS; SuperSOT-3
R44, R45, R46: 100 1% 1/5W; R_0603_1608Metric_Pad0.98x0.95mm_HandSolder
R47, R48: 150; R_0603_1608Metric_Pad0.98x0.95mm_HandSolder
R49, R50: 100k 1% 1/5W; R_0603_1608Metric_Pad0.98x0.95mm_HandSolder

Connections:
+3.3V: R46.1; also elsewhere on the board
+5V: R47.1, R48.1; also elsewhere on the board
/Project_Architecture/Indication - USR/LED_1_D: D9.1 (K), Q1.1 (D)
/Project_Architecture/Indication - USR/LED_1_G: Q1.2 (G), R44.1
/Project_Architecture/Indication - USR/LED_1_R: D9.2 (A), R47.2
/Project_Architecture/Indication - USR/LED_2_D: D10.1 (K), Q2.1 (D)
/Project_Architecture/Indication - USR/LED_2_G: Q2.2 (G), R45.1
/Project_Architecture/Indication - USR/LED_2_R: D10.2 (A), R48.2
/Project_Architecture/Indication - USR/PWR_LED: D7.2 (A), R46.2
/Project_Architecture/Indication - USR/USR_LED_1: R44.2, R49.1; also elsewhere on the board
/Project_Architecture/Indication - USR/USR_LED_2: R45.2, R50.1; also elsewhere on the board
GND1: D7.1 (K), Q1.3 (S), Q2.3 (S), R49.2, R50.2; also elsewhere on the board

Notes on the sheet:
DESIGN NOTE : PWR LED(RED): Vf = 2V R =(3.3V - 2V)/20mA = 65Ohm ~ 70Ohm P =(3.3V - 2V)*20mA = 26mW Size : 0603
PART NO: FDN359BN
Part No: 150060VS75000
Part No: 150060RS75000
DESIGN NOTE : USR LED(GREEN): Vf = 2V R =(5V - 2V)/20mA = 150Ohm P =(5V - 2V)*20mA = 60mW Size : 0603
[${#}] ${SHEETNAME}
USER Led
Power Led

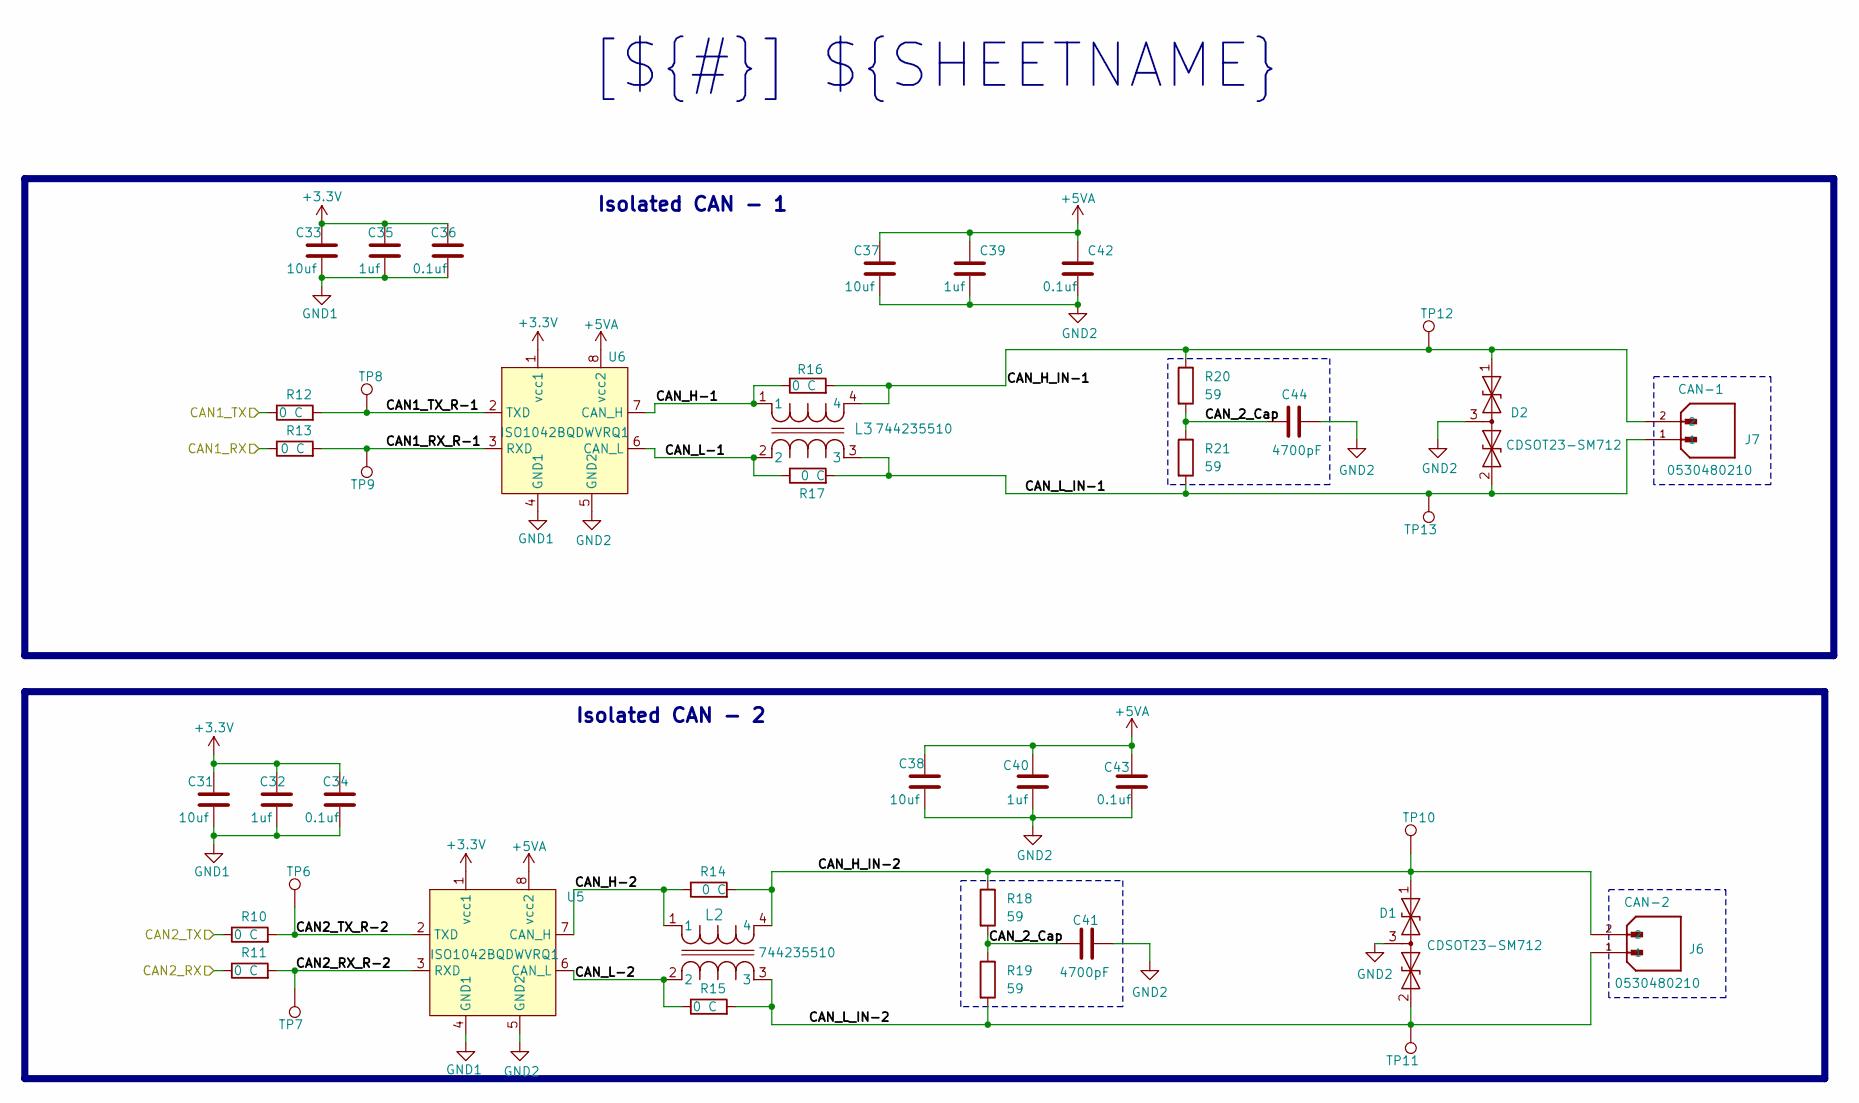
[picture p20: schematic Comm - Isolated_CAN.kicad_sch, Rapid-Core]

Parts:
C31, C33, C37, C38: 10uf; C_0805_2012Metric_Pad1.18x1.45mm_HandSolder
C32, C35, C39, C40: 1uf; C_0603_1608Metric_Pad1.08x0.95mm_HandSolder
C34, C36, C42, C43: 0.1uf; C_0603_1608Metric_Pad1.08x0.95mm_HandSolder
C41, C44: 4700pF; C_0805_2012Metric_Pad1.18x1.45mm_HandSolder
D1: SM712_SOT23; SOT-23; MANUFACTURER PART NO CDSOT23-SM712
D2: SM712_SOT23; SOT-23; Manufacturer Part No CDSOT23-SM712
J6: CAN-2; MOLEX_530480210; PARTREV A
J7: CAN-1; MOLEX_530480210; PARTREV A
L2, L3: ACT45B-510-2P-TL003; IND_ACT45R_TDK; MANUFACTURER PART NO 744235510
R10, R11, R12, R13, R14, R15, R16, R17: 0 C; R_0805_2012Metric_Pad1.20x1.40mm_HandSolder
R18, R19, R20, R21: 59; R_0603_1608Metric_Pad0.98x0.95mm_HandSolder
TP6, TP7, TP8, TP9, TP10, TP11, TP12, TP13: TestPoint; TestPoint_Pad_D1.0mm
U5, U6: ISO1042BQDWVRQ1; IC_AMC1311BQDWVQ1

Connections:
+3.3V: C31.1, C32.1, C33.1, C34.2, C35.1, C36.2, U5.1 (vcc1), U6.1 (vcc1); also elsewhere on the board
+5VA: C37.1, C38.1, C39.1, C40.1, C42.2, C43.2, U5.8 (vcc2), U6.8 (vcc2); also elsewhere on the board
/Project_Architecture/Comm - Isolated_CAN/CAN1_RX: R13.1; also elsewhere on the board
/Project_Architecture/Comm - Isolated_CAN/CAN1_RX_R-1: R13.2, TP9.1, U6.3 (RXD)
/Project_Architecture/Comm - Isolated_CAN/CAN1_TX: R12.1; also elsewhere on the board
/Project_Architecture/Comm - Isolated_CAN/CAN1_TX_R-1: R12.2, TP8.1, U6.2 (TXD)
/Project_Architecture/Comm - Isolated_CAN/CAN2_RX: R11.1; also elsewhere on the board
/Project_Architecture/Comm - Isolated_CAN/CAN2_RX_R-2: R11.2, TP7.1, U5.3 (RXD)
/Project_Architecture/Comm - Isolated_CAN/CAN2_TX: R10.1; also elsewhere on the board
/Project_Architecture/Comm - Isolated_CAN/CAN2_TX_R-2: R10.2, TP6.1, U5.2 (TXD)
/Project_Architecture/Comm - Isolated_CAN/CAN_2_Cap: C41.1, C44.1, R18.2, R19.1, R20.2, R21.1
/Project_Architecture/Comm - Isolated_CAN/CAN_H-1: L3.1, R16.1, U6.7 (CAN_H)
/Project_Architecture/Comm - Isolated_CAN/CAN_H-2: L2.1, R14.1, U5.7 (CAN_H)
/Project_Architecture/Comm - Isolated_CAN/CAN_H_IN-1: D2.1 (A1), J7.2, L3.4, R16.2, R20.1, TP12.1
/Project_Architecture/Comm - Isolated_CAN/CAN_H_IN-2: D1.1 (A1), J6.2, L2.4, R14.2, R18.1, TP10.1
/Project_Architecture/Comm - Isolated_CAN/CAN_L-1: L3.2, R17.1, U6.6 (CAN_L)
/Project_Architecture/Comm - Isolated_CAN/CAN_L-2: L2.2, R15.1, U5.6 (CAN_L)
/Project_Architecture/Comm - Isolated_CAN/CAN_L_IN-1: D2.2 (A2), J7.1, L3.3, R17.2, R21.2, TP13.1
/Project_Architecture/Comm - Isolated_CAN/CAN_L_IN-2: D1.2 (A2), J6.1, L2.3, R15.2, R19.2, TP11.1
GND1: C31.2, C32.2, C33.2, C34.1, C35.2, C36.1, U5.4 (GND1), U6.4 (GND1); also elsewhere on the board
GND2: C37.2, C38.2, C39.2, C40.2, C41.2, C42.1, C43.1, C44.2, D1.3 (common), D2.3 (common), U5.5 (GND2), U6.5 (GND2); also elsewhere on the board

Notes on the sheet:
Isolated CAN - 1
Isolated CAN - 2
[${#}] ${SHEETNAME}

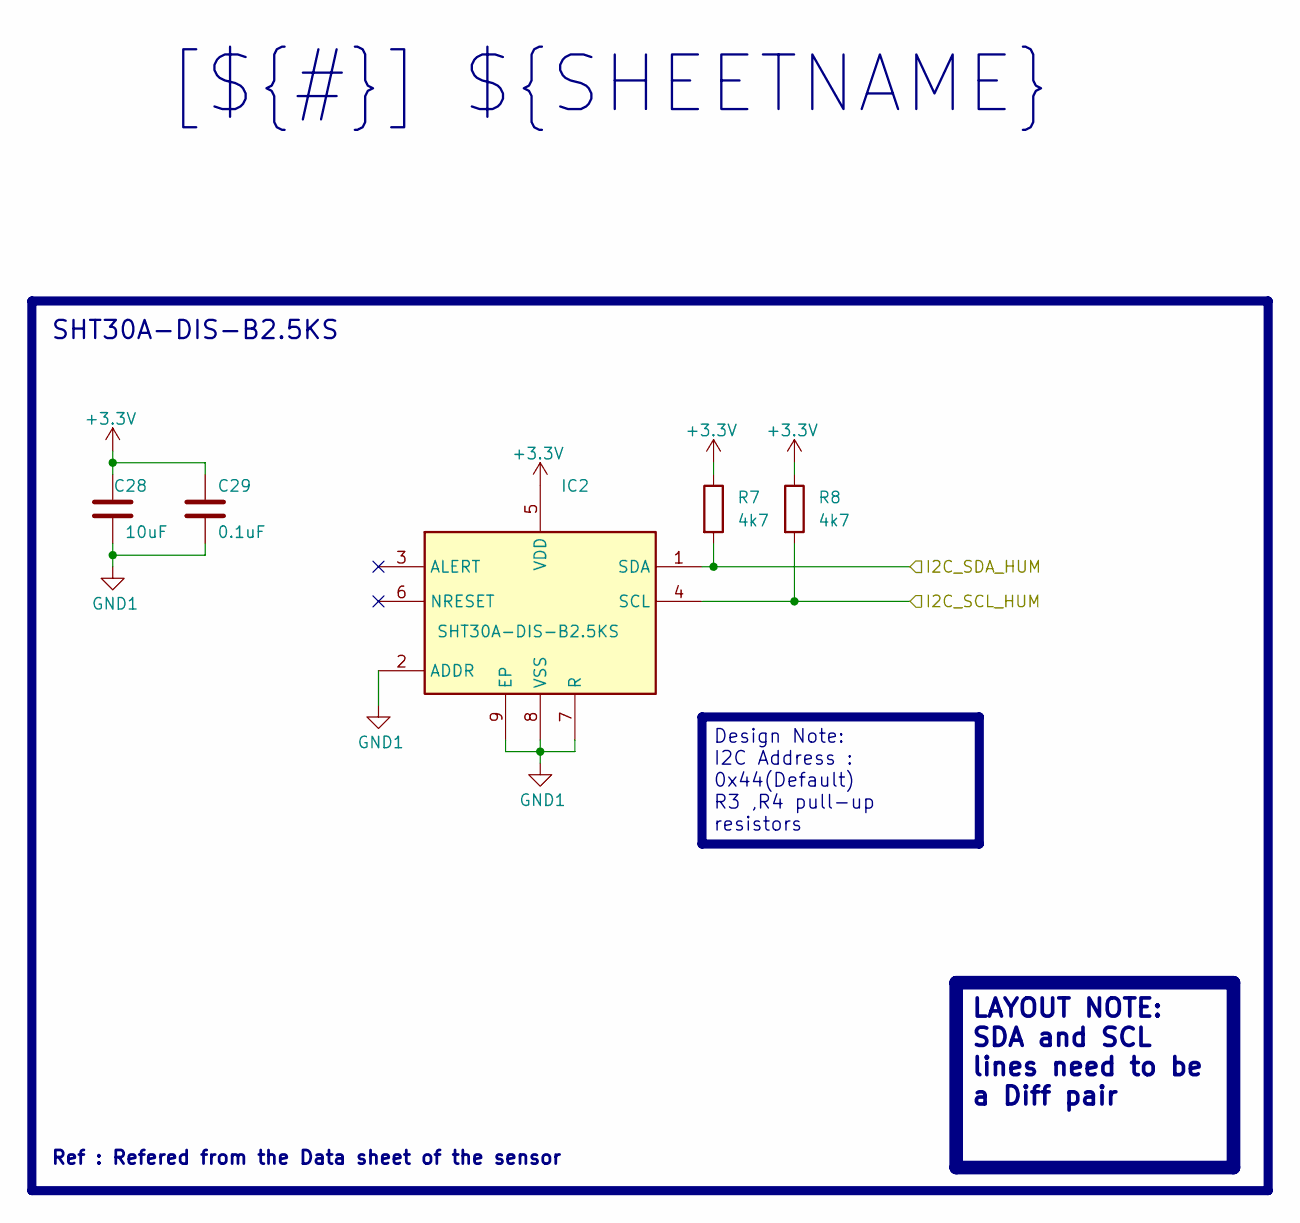
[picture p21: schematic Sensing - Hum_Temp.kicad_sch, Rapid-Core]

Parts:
C28: 10uF; C_0805_2012Metric_Pad1.18x1.45mm_HandSolder
C29: 0.1uF; C_0603_1608Metric_Pad1.08x0.95mm_HandSolder
IC2: SHT30A-DIS-B2.5KS; SON50P250X250X100-9N-D; Mouser Part Number 403-SHT30ADIS-B2.5KS
R7, R8: 4k7; R_0805_2012Metric_Pad1.20x1.40mm_HandSolder

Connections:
+3.3V: C28.1, C29.1, IC2.5 (VDD), R7.1, R8.1; also elsewhere on the board
/Project_Architecture/MCU/I2C_SCL_HUM: IC2.4 (SCL), R8.2; also elsewhere on the board
/Project_Architecture/MCU/I2C_SDA_HUM: IC2.1 (SDA), R7.2; also elsewhere on the board
GND1: C28.2, C29.2, IC2.2 (ADDR), IC2.7 (R), IC2.8 (VSS), IC2.9 (EP); also elsewhere on the board

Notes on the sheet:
Design Note: I2C Address : 0x44(Default) R3 ,R4 pull-up resistors
LAYOUT NOTE: SDA and SCL lines need to be a Diff pair
[${#}] ${SHEETNAME}
Ref : Refered from the Data sheet of the sensor
SHT30A-DIS-B2.5KS

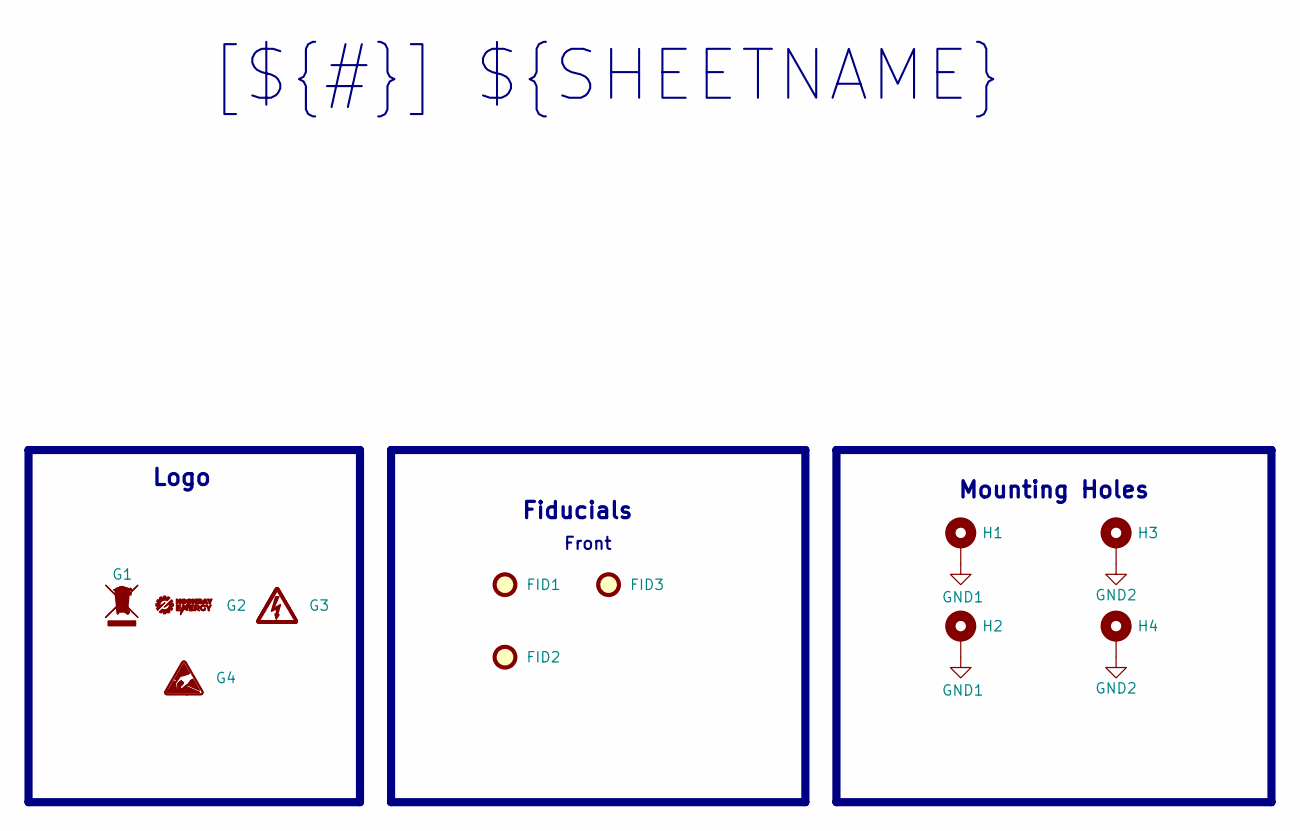
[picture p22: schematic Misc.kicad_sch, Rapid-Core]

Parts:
FID1, FID2, FID3: Fiducial; Fiducial_1.5mm_Mask3mm
G1: Not_to_bin; Not_To_Bin
G2: NOON_REAY_ENERGIES; Noon_Ray
G3: High_Voltage_Warning
G4: ESD_Protection; ESD_Protection_Sign
H1, H2, H3, H4: MountingHole_Pad; MountingHole_2.2mm_M2_Pad

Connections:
GND1: H1.1, H2.1; also elsewhere on the board
GND2: H3.1, H4.1; also elsewhere on the board

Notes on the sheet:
Front
[${#}] ${SHEETNAME}
Mounting Holes
Logo
Fiducials

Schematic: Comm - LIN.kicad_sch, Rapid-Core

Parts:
C45, C46: 220uF, 0805; C_0805_2012Metric_Pad1.18x1.45mm_HandSolder
C47, C49: 10uF, 10V, 0805; C_0805_2012Metric_Pad1.18x1.45mm_HandSolder
C48, C50: 0u1F, 10V, 0603; C_0603_1608Metric_Pad1.08x0.95mm_HandSolder
D3, D4: D; D_SOD-323_HandSoldering
IC3, IC4: TLIN1039DDFRQ1; SOT65P280X110-8N; Mouser Part Number 595-TLIN1039DDFRQ1
J8: LIN-2; PinHeader_1x02_P2.54mm_Vertical
J9: LIN-1; PinHeader_1x02_P2.54mm_Vertical
J10: LIN-1; MOLEX_530480210; PARTREV A
J11: LIN-2; MOLEX_530480210; PARTREV A
R22, R23: 10K; R_0805_2012Metric_Pad1.20x1.40mm_HandSolder
R24, R25: 1k; R_0805_2012Metric_Pad1.20x1.40mm_HandSolder
TP14, TP15: TestPoint; TestPoint_Pad_D1.0mm

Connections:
+5V: C47.1, C48.1, C49.1, C50.1, D3.2 (A), D4.2 (A), IC3.7 (VSUP), IC4.7 (VSUP), R22.1, R23.1; also elsewhere on the board
/Project_Architecture/Comm - LIN/LIN1: C45.1, IC3.6 (LIN), J9.2, J10.2, TP15.1
/Project_Architecture/Comm - LIN/LIN1_CMD: D4.1 (K), R25.2
/Project_Architecture/Comm - LIN/LIN1_CMD_R: J9.1, R25.1
/Project_Architecture/Comm - LIN/LIN1_EN: IC3.2 (EN); also elsewhere on the board
/Project_Architecture/Comm - LIN/LIN1_RX: IC3.1 (RXD), R23.2; also elsewhere on the board
/Project_Architecture/Comm - LIN/LIN1_TX: IC3.4 (TXD); also elsewhere on the board
/Project_Architecture/Comm - LIN/LIN2: C46.1, IC4.6 (LIN), J8.2, J11.2, TP14.1
/Project_Architecture/Comm - LIN/LIN2_CMD: D3.1 (K), R24.2
/Project_Architecture/Comm - LIN/LIN2_CMD_R: J8.1, R24.1
/Project_Architecture/Comm - LIN/LIN2_EN: IC4.2 (EN); also elsewhere on the board
/Project_Architecture/Comm - LIN/LIN2_RX: IC4.1 (RXD), R22.2; also elsewhere on the board
/Project_Architecture/Comm - LIN/LIN2_TX: IC4.4 (TXD); also elsewhere on the board
GND1: C45.2, C46.2, C47.2, C48.2, C49.2, C50.2, IC3.5 (GND), IC4.5 (GND), J10.1, J11.1; also elsewhere on the board

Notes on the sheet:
Part No: D3 : 1N4448WSF-7
Part No: D4 : 1N4448WSF-7
DESIGN NOTE: 1. If J9 is closed the tranceiver acts a Commander. 2. If J9 is open the transceiver acts a Responder.
PWR LIN_2
[${#}] ${SHEETNAME}
LIN - 2
LIN - 1

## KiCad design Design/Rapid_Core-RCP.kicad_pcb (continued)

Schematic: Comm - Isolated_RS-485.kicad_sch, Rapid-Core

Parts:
C51, C52, C57, C58: 0.1uf; C_0603_1608Metric_Pad1.08x0.95mm_HandSolder
C53, C54, C59, C61: 1uf; C_0603_1608Metric_Pad1.08x0.95mm_HandSolder
C55, C56, C62, C64: 10uf; C_0805_2012Metric_Pad1.18x1.45mm_HandSolder
C60, C63: 4700pF; C_0805_2012Metric_Pad1.18x1.45mm_HandSolder
D5: SM712_SOT23; SOT-23; MANUFACTURER PART NO CDSOT23-SM712
D6: SM712_SOT23; SOT-23
J12: RS-485-1; MOLEX_530480210; MANUFACTURER PART NO 0530480210
J13: RS-485-2; MOLEX_530480210; PARTREV A
L4, L5: ACT45B-510-2P-TL003; IND_ACT45R_TDK; MANUFACTURER PART NO 744235510
R26, R27, R28, R29, R30, R31, R32, R33, R34, R35: 0 RS; R_0805_2012Metric_Pad1.20x1.40mm_HandSolder
R36, R37, R38, R39: 10k , RS; R_0805_2012Metric_Pad1.20x1.40mm_HandSolder
R40, R41, R42, R43: 59; R_0603_1608Metric_Pad0.98x0.95mm_HandSolder
TP16, TP17, TP18, TP19, TP20, TP21, TP22, TP23, TP24, TP25: TestPoint; TestPoint_Pad_D1.0mm
U7, U8: ISO3082DW; SOIC-16W_7.5x10.3mm_P1.27mm

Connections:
+3.3V: C51.1, C52.1, C53.1, C54.1, C55.2, C56.2, U7.1 (Vcc1), U8.1 (Vcc1); also elsewhere on the board
+5VA: C57.1, C58.1, C59.1, C61.1, C62.2, C64.2, R37.2, R39.2, U7.16 (Vcc2), U8.16 (Vcc2); also elsewhere on the board
/Project_Architecture/Comm - Isolated_RS-485/RS-485_1_Cap: C60.1, R40.2, R41.1
/Project_Architecture/Comm - Isolated_RS-485/RS-485_1_EN: R28.1; also elsewhere on the board
/Project_Architecture/Comm - Isolated_RS-485/RS-485_1_EN_R-1: R28.2, TP19.1, U7.4 (~RE), U7.5 (DE)
/Project_Architecture/Comm - Isolated_RS-485/RS-485_1_RX: R27.1; also elsewhere on the board
/Project_Architecture/Comm - Isolated_RS-485/RS-485_1_RX_R-1: R27.2, TP20.1, U7.3 (R)
/Project_Architecture/Comm - Isolated_RS-485/RS-485_1_TX: R26.1; also elsewhere on the board
/Project_Architecture/Comm - Isolated_RS-485/RS-485_1_TX_R-1: R26.2, TP16.1, U7.6 (D)
/Project_Architecture/Comm - Isolated_RS-485/RS-485_2_Cap: C63.1, R42.2, R43.1
/Project_Architecture/Comm - Isolated_RS-485/RS-485_2_EN: R31.1; also elsewhere on the board
/Project_Architecture/Comm - Isolated_RS-485/RS-485_2_EN_R-2: R31.2, TP21.1, U8.4 (~RE), U8.5 (DE)
/Project_Architecture/Comm - Isolated_RS-485/RS-485_2_RX: R30.1; also elsewhere on the board
/Project_Architecture/Comm - Isolated_RS-485/RS-485_2_RX_R-2: R30.2, TP18.1, U8.3 (R)
/Project_Architecture/Comm - Isolated_RS-485/RS-485_2_TX: R29.1; also elsewhere on the board
/Project_Architecture/Comm - Isolated_RS-485/RS-485_2_TX_R-2: R29.2, TP17.1, U8.6 (D)
/Project_Architecture/Comm - Isolated_RS-485/RS-485_A-1: L4.2, R33.1, R39.1, U7.12 (A)
/Project_Architecture/Comm - Isolated_RS-485/RS-485_A-2: L5.2, R34.1, R37.1, U8.12 (A)
/Project_Architecture/Comm - Isolated_RS-485/RS-485_A-IN-1: D5.2 (A2), J12.1, L4.3, R33.2, R41.2, TP23.1
/Project_Architecture/Comm - Isolated_RS-485/RS-485_A_IN-2: D6.2 (A2), J13.1, L5.3, R34.2, R43.2, TP25.1
/Project_Architecture/Comm - Isolated_RS-485/RS-485_B-1: L4.1, R32.1, R38.1, U7.13 (B)
/Project_Architecture/Comm - Isolated_RS-485/RS-485_B-2: L5.1, R35.1, R36.1, U8.13 (B)
/Project_Architecture/Comm - Isolated_RS-485/RS-485_B_IN-1: D5.1 (A1), J12.2, L4.4, R32.2, R40.1, TP22.1
/Project_Architecture/Comm - Isolated_RS-485/RS-485_B_IN-2: D6.1 (A1), J13.2, L5.4, R35.2, R42.1, TP24.1
GND1: C51.2, C52.2, C53.2, C54.2, C55.1, C56.1, U7.2 (GND1), U7.7 (GND1), U7.8 (GND1), U8.2 (GND1), U8.7 (GND1), U8.8 (GND1); also elsewhere on the board
GND2: C57.2, C58.2, C59.2, C60.2, C61.2, C62.1, C63.2, C64.1, D5.3 (common), D6.3 (common), R36.2, R38.2, U7.9 (GND2), U7.10 (GND2), U7.15 (GND2), U8.9 (GND2), U8.10 (GND2), U8.15 (GND2); also elsewhere on the board

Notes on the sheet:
[${#}] ${SHEETNAME}
Isolated RS_485 - 2
RS-485 2
Isolated RS_485 - 1

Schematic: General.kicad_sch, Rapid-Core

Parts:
C30: 0u1F; C_0603_1608Metric_Pad1.08x0.95mm_HandSolder
J2: GPIO_CONN_X_4; PinHeader_1x06_P2.54mm_Vertical
J3: SPI; PinHeader_1x05_P2.54mm_Vertical
J4: USART; PinHeader_1x04_P2.54mm_Vertical
J5: SWD_Debug; PinHeader_1x05_P2.54mm_Vertical
R9: 10k; R_0805_2012Metric_Pad1.20x1.40mm_HandSolder; not fitted
SW1: SW_Push; SW_Tactile_SPST_NO_Straight_CK_PTS636Sx25SMTRLFS

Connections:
+3.3V: J2.1, J3.1, J4.1, J5.1, R9.2; also elsewhere on the board
/Project_Architecture/GPIO/GPIO_1_PB0: J2.2; also elsewhere on the board
/Project_Architecture/GPIO/GPIO_1_PB1: J2.3; also elsewhere on the board
/Project_Architecture/GPIO/GPIO_1_PB2: J2.4; also elsewhere on the board
/Project_Architecture/GPIO/GPIO_1_PB3: J2.5; also elsewhere on the board
/Project_Architecture/GPIO/NRST: C30.1, J5.3, R9.1, SW1.1; also elsewhere on the board
/Project_Architecture/GPIO/SPI1_MISO: J3.3; also elsewhere on the board
/Project_Architecture/GPIO/SPI1_MOSI: J3.4; also elsewhere on the board
/Project_Architecture/GPIO/SPI1_SCK: J3.2; also elsewhere on the board
/Project_Architecture/GPIO/SWDIO: J5.4; also elsewhere on the board
/Project_Architecture/GPIO/SW_CLK: J5.2; also elsewhere on the board
/Project_Architecture/GPIO/USART2_RX: J4.3; also elsewhere on the board
/Project_Architecture/GPIO/USART2_TX: J4.2; also elsewhere on the board
GND1: C30.2, J2.6, J3.5, J4.4, J5.5, SW1.2; also elsewhere on the board

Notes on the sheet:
DESCRIPTION: External USART/UART device can be connected ex: Memory card or any other sensors
DESCRIPTION: External GPIO Controllable Devices can be connected and controlled
DESCRIPTION: External SPI device can be connected ex: Memory card or any other sensors
LAYOUT NOTE: Do not use via on clk and IO line
DESCRIPTION: Debug Interface for MCU
Part No: SW1 : PTS636SK25FSMTR LFS
External SPI
SWD Debug
[${#}] ${SHEETNAME}
NRST Button
External USART/UART
GPIO Pins

Board: 4 copper layers, 194 parts (0 on the bottom side), 93 nets, no tracks yet.

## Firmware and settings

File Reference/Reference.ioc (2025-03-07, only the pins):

Mcu.UserName=STM32H750VBTx
PA1.GPIO_Label=LIN2_EN
PA1.Signal=GPIO_Output
PA10.GPIO_Label=LIN_RX_2
PA10.Signal=USART1_RX
PA11.GPIO_Label=LIN_EN_2
PA11.Signal=GPIO_Output
PA2.GPIO_Label=LIN2_TX
PA2.Signal=USART2_TX
PA3.GPIO_Label=LIN2_RX
PA3.Signal=USART2_RX
PA5.Signal=SPI1_SCK
PA6.Signal=SPI1_MISO
PA7.Signal=SPI1_MOSI
PA9.GPIO_Label=LIN_TX_2
PA9.Signal=USART1_TX
PB0.Signal=ADCx_INP9
PB1.Signal=ADCx_INP5
PB10.GPIO_Label=I2C_SCL_1
PB10.Signal=I2C2_SCL
PB11.GPIO_Label=I2C_SDA_1
PB11.Signal=I2C2_SDA
PB12.GPIO_Label=SPI_NSS/CS
PB12.Signal=SPI2_NSS
PB13.GPIO_Label=SPI_SCK_FLASH
PB13.Signal=SPI2_SCK
PB14.GPIO_Label=SPI_MISO_FLASH
PB14.Signal=SPI2_MISO
PB15.GPIO_Label=SPI_MOSI_FLASH
PB15.Signal=SPI2_MOSI
PB2.GPIO_Label=GPIO_1
PB2.Signal=GPIO_Output
PB5.Signal=FDCAN2_RX
PB6.Signal=FDCAN2_TX
PB8.Signal=FDCAN1_RX
PB9.Signal=FDCAN1_TX
PC10.GPIO_Label=RS_485_TX_1
PC10.Signal=UART4_TX
PC11.GPIO_Label=RS_485_RX_1
PC11.Signal=UART4_RX
PC12.GPIO_Label=RS_485_EN_1
PC12.Signal=GPIO_Output
PC4.Signal=ADCx_INP4
PC5.Signal=ADCx_INP8
PC6.Signal=USART6_TX
PC7.Signal=USART6_RX
PC8.Signal=USART6_CK
PD12.GPIO_Label=I2C_SCL_HUM
PD12.Signal=I2C4_SCL
PD13.GPIO_Label=I2C_SDA_HUM
PD13.Signal=I2C4_SDA
PD7.GPIO_Label=RS_485_EN_2
PD7.Signal=GPIO_Output
PD8.GPIO_Label=SPI_HOLD_FLASH
PD8.Signal=GPIO_Output
PD9.GPIO_Label=SPI_WP_FLASH
PD9.Signal=GPIO_Output
PE10.GPIO_Label=GPIO_5
PE10.Signal=GPIO_Output
PE11.GPIO_Label=GPIO_6
PE11.Signal=GPIO_Output
PE12.GPIO_Label=GPIO_7
PE12.Signal=GPIO_Output
PE13.GPIO_Label=GPIO_8
PE13.Signal=GPIO_Output
PE14.GPIO_Label=GPIO_9
PE14.Signal=GPIO_Output
PE15.GPIO_Label=GPIO_10
PE15.Signal=GPIO_Output
PE3.GPIO_Label=USR_LED_1
PE3.Signal=GPIO_Output
PE4.GPIO_Label=USR_LED_2
PE4.Signal=GPIO_Output
PE7.GPIO_Label=GPIO_2
PE7.Signal=GPIO_Output
PE8.GPIO_Label=GPIO_3
PE8.Signal=GPIO_Output
PE9.GPIO_Label=GPIO_4
PE9.Signal=GPIO_Output

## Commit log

2024-09-11 Added All files
    [Communication_interface.kicad_sch, Rapid_Core-RCP.kicad_pcb, Rapid_Core-RCP.kicad_sch]
2024-09-12 Added Comps in Communication.sch
    [Communication_interface.kicad_sch, Rapid_Core-RCP.kicad_sch]
2024-09-12 Added reference file for chokless CAN and DC-DC converter in main sch
    [Communication_interface.kicad_sch, Rapid_Core-RCP.kicad_sch]
2024-09-13 Communication.sch modified , 75% finished
    [Communication_interface.kicad_sch, Rapid_Core-RCP.kicad_sch]
2024-09-14 Added HUM and TEMP sense
    [Communication_interface.kicad_sch, Rapid_Core-RCP.kicad_sch]
2024-09-16 LIN,I2C,SPI,SWD added , Power_stage created
    [Communication_interface.kicad_sch, Power_stage.kicad_sch, Rapid_Core-RCP.kicad_sch]
2024-09-17 Setup Power supply
    [Communication_interface.kicad_sch, Power_stage.kicad_sch, Rapid_Core-RCP.kicad_sch]
2024-09-18 Footprints added to all componenets
    [Communication_interface.kicad_sch, Power_stage.kicad_sch, Rapid_Core-RCP.kicad_sch]
2024-09-18 CMC component name added
    [Communication_interface.kicad_sch, Power_stage.kicad_sch, Rapid_Core-RCP.kicad_sch]
2024-09-19 Schematic Design complete
    [Communication_interface.kicad_sch, Power_stage.kicad_sch, Rapid_Core-RCP.kicad_pcb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]
2024-09-24 PCB design started, comps arranged
    [Communication_interface.kicad_sch, Power_stage.kicad_sch, Rapid_Core-RCP.kicad_pcb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]
2024-09-26 Temp complete of communication section , added Safety caps
    [Communication_interface.kicad_sch, Rapid_Core-RCP.kicad_pcb, Rapid_Core-RCP.kicad_sch]
2024-09-27 value changed for I2C pullup
    [Rapid_Core-RCP.kicad_sch]
2024-10-04 Added all the sections
    [Power_stage.kicad_sch, Rapid_Core-RCP.kicad_pcb, Rapid_Core-RCP.kicad_sch]
2024-10-08 Added lib folder, Layer layed
    [Communication_interface.kicad_sch, Power_stage.kicad_sch, Rapid_Core-RCP.kicad_pcb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]
2024-10-14 End of version 1.0.0 design
    [Power_stage.kicad_sch, Rapid_Core-RCP.kicad_pcb, Rapid_Core-RCP.kicad_sch]
2024-10-30 Added everything
    [Communication_interface.kicad_sch, Power_stage.kicad_sch, Rapid_Core-RCP.kicad_pcb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]
2024-11-09 Added Information to all the sheets
    [Block_Diagram.kicad_sch, CAN.kicad_sch, Comm - Isolated_CAN.kicad_sch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]
2024-11-23 Layout complete
    [CAN.kicad_sch, Comm - Isolated_CAN.kicad_sch, Comm - Isolated_RS-485.kicad_sch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]
2024-11-25 Project finished , man files generated
    [Block_Diagram.kicad_sch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]
2025-03-07 new Design for Prototyping
    [Block_Diagram.kicad_sch, Comm - Isolated_CAN.kicad_sch, Comm - Isolated_RS-485.kicad_sch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]

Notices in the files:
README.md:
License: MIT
